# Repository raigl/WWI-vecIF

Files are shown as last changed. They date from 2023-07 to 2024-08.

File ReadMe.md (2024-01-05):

# Whirlwind I Vector Graphics Interface

For showing a Whirlwind programme's output, a small hardware
generates vector strokes on X/Y/Z oszilloskopes
and allows to attach light guns.
Guy Fedorkow's WWI simulator ([https://github.com/gfedorkow/Whirlwind-Instruction-Simulator]) running on a Raspberry (B+) 
can drive the interface and run some original WWI programmes.

## Directories

<dl>
<dt> CAD   <dd> 3D Light gun case 3D files 
<dt> DOC   <dd> Documentation (own and collected)  
<dt> KiCad <dd> Schematics and PCB drawings
<dt> src   <dd> Python and Arduino source
</dl>

## Versions

0.3     Working prototype

1.0     Redesigned

## Basics

The interface allows to draw (short) vectors for two channels
on an analog x/y/z display, e.g. an oszilloscope.
Points are drawn as zero-length vectors.

The D/A converter used has an internal reference of 2.048V, 12 bits
resolution and produces 0..2.047V in steps of 1/4096. 
WWI uses 10 bits plus sign, i.e. +/- 1023.
Thus the coordinate unit corresponds to 1mV internally.
The output state amplifies by 3 (and shifts to zero base), 
thus supplies +/- 3V and 3mV per unit. 

Drawing a vector is done by setting two integrators to the start point,
then provide a speed and start the integrators for 50µs,
which at the same time provides a strobe for the z axis.
With maximum speed (-1023 or +1023, i.e. 0 or 2.047V), the movement is 1/8 of the full coordinate range -1.0 .. +1.0,
i.e. 256 coordinate units or 250mV. 
Thus coordinate differences must be multiplied by 4 to set the speed. 
Longer vectors must be drawn as segments.

The display should be setup such that increasing both coordinates
moves the point right and up.

Character display is not done by hardware as in WWI,
but by software as a chain of segments;
this requires a precise setup of the mid voltage
to 1.023V; otherwise the characters are blurred.

Vector drawing was inspried by the Vectrex gaming console.
Original WWI hardware used a more elaborate method:
A fixed ramp generator (for each coordinate) was multiplied by
the vector delta coordinate provided. 
The advantage is that the end points and do not depend on the precision of the integration capacitor.
Also the strobe start and end could be slightly before and after the end of the ramp, 
ensuring that a chain of vectors has no gaps.

## Displays
 
To display the vectors, the display device must have analog inputs for X/Y mode
and a (digital) Z input for intensitiy modulation.

To better mimic the original, the vector interface board provides
a display bus connector to be used with one or more display tap boards,
which are located directly near a display.

Each display tap board has two switches to select one or both intensification
lines (the original had 15). 

A light gun (light pen) for interactive mode can be connected to a display tap board
and configured for one of two light gun inputs.

Four more switches with lamps (LEDs) can be set by either the user or WWI 
programme.

Displays could in particular be oszilloscopes with a trace blanking
or unblanking input (Z-input).
The amplitude of the X and Y signals is &plusmn;3V which can be attenuated
with a potentiometer on the board.
Z output is 5V (TTL) digital output with 50µs active pulses.
Polarity can be configured on the tap board.

Displays that work without modifications are:
- Grundig GO-40Z oszilloscope (with Z-option)
- Tektronix 1740A oszilloscope 
- Tektronix 611 storage display unit

The Tektronix 611 can be swiched to non-storage mode and is normally 
internally wired for +/- 1V sensitivity; 
thus the potentimeters on the tap board are required.

Several other oscilloscopes have a Z option, but often require
at least 20V to blank the trace.
For this cases, a variant of the tap board has provisions for a voltage converter
and corresponding output amplifier.
Some (e.g. Hameg) are designed for blanking small parts of the trace
only by a diode clamp for the coupling capacitor;
this diode has to be removed or reversed, otherwise the blanking would not work.
 
A Hameg HM512 was succesfully modified by reversing the diode and also
adding internally a small amplifier to obtain larger voltage swing
from the Z-input. 

## I²C Bus

The interface board has a connection to access the Rapi's (second) I²C bus,
shifted to 5V operation.

With upto eight PCF8574, each can drive 8 swiches and lamps.

Note that the WWI had no console, but was to a large extend controlled
by panel switches and lights.

## 5V only operation

The board can be driven by a 5V Arduino.
In this case, JP3 must be cut and changed.
The voltage stablizer U9 (LP 2950-3.3) must be used.
The 3.3V pins are then supplied with 5V.

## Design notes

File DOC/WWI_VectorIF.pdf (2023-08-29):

# Whirlwind I Hardware Vector Interface

Rainer Glaschick, Paderborn 2023-05-13 2023-08-29

# Revision target

For the transition to the revised Interface that will be version 1.0, the planned changes are described below.

Using a display bus and additional tap boards better models the original situation, even if there are currently only two displays useable.

In any case, the selection of the output intensification is done via switches on (or connected to) the tap boards (and not per software).

To have a bank of switches and LEDs, the I²C bus is available on a second connector (4 pins).

## Output

Instead of two outputs for X/Y/Z and two connectors for Lightguns, a display bus is used with tap boards. The number of pins depends on the amount of logic in the tap boards and corresponding flexibility.

In case that rugged connections with proper (round, not ribbon) cables are required, use of the common 15-pin D-SUB connectors is proposed using these lines:

X, Y
Z1, Z2
L1, L2
+5V
GPIO27 (Push-Button)
GPIO5, GPIO6, GPIO20, GPIO21
3x GND

Inversion of the intensification signals Z1 and Z2 is provided on the tap boards, as this uses only two MOS-FETs (and a switch).

The GPIO27 is the same as the key on the interface and may be connected to ground by a momentary push button on the tap board. No LEDs should be connected to this button. Preferred use is as exit if pressed more than 1 sec (software feature).

The other four GPIO lines are logically open-collector lines that can sink upto 2mA each. If grounded by a switch (or key), software can determine the low state (which also lights the LED) and act accordingly.

All GPIO-lines have pullup resistors of 15k (5V) and 10k (3.3V) and are bidirectional converted from 3.3V to 5V, see NXP AN10441.

As a soldering option, instead of GPIO20 and GPIO21, the inverted intensification signals may be used, as this is just a layout option.

If a smaller connector is desired, a 9 pin D-Sub may be used; the pin layout provides X, Y, Z1, Z2, L1, L2, 5V and 2x ground, thus no keys or lamps and no inverted intensification.

On the board, a 2.54mm 2x8 pin header for ribbon connectors is used, pin 16 unused.

## Tap board

A tap board has at least:

two trim potentioemeters (10 kΩ) for the X and Y outputs two (manual) switches to select Z1 or Z2 or both.
one light gun connection
one pushbutton
four switches with LEDs

To select both, Z1 and Z2, schottky diodes driving a 6.8kΩ resistor should work well, although (short) vectors and

Whirlwind I Hardware Vector Interface | 1/5
R. Glaschick, Paderborn | 29.08.23

character segments might be slightly shortened. In that case, CMOS invertes should be used. (The time constant for a 100pF load is 0.68µs, which is less than 2% of the 50µs strobe signal). Another configuration switch (not to be used during normal operation) inverts the intensification signal.

The pushbutton and the switches are described in the previous section.

While two lightguns driving the same line will not damage the system, a configuration jumper should be used to select the light gun input line, not a switch to change it while in operation.

A special tap board may contain a voltage booster providing 30V from the 5V supply to have a larger voltage swing at the Z connector to the display, in particular for older oscilloscopes.

## I²C Bus

By providing the I²C bus on a connector of its own, a bank of panel switches and lights may be connected. Upto 8 PCF 8574 port expanders for 8 lamps or switches may be used.

As with the tap board, the outputs of the port expander are open-drain, here with a dynamic and static pullup.

So each line will lighten the lamp if connected to ground, and either the user or the computer can connect to ground (and light the lamp).

It the computer wants to find out the switches, it would temporarily switch all off and see which ones are still on. Same procedure for the user.

## Reference voltage

A reference of 1.024V is required for the integrators to define the zero speed for displaying points.

The output amplifiers are designed for a 3.3V reference to change the internal 1.024±1.024V to symmetrical ±3.076V.

The board may either use a LP2950-3.3 linear regulator from 5V, or use the 3.3V from the Raspi board directly.

For the integrator's 1.024V, either a trim pot is used to calibrate the voltage.

The output's zero voltage and amplitude is normally not very critical. A voltage divider with 12kΩ and 10kΩ is used giving fairly good results. Place for two larger resistors, e.g. 100kΩ and 150kΩ, is provided for better results, depending on the accuracy of the 3.3V reference.

## 5V protection

A 0.5A fuse is inserted just before the connector to the Raspi. Normally more current can be drawn, only limited by the power supply (minus the current drawn be the Raspi and connected USB perpherals) and the copper tracks on the Raspi. So the tap boards should not use more then 0.4A together, i.e. 0.2A or 1W each for two.

## Integrator switches

The standard 4066 CMOS switches actually work fine; the vertical detours seen on the TEK 611 have not manifested on the oscilloscopes used so far. And because it is only on the horizontal signal, it might be a hardware problem of the TEK 611, Although the datasheet for the 4066 gives gives 50mV crosstalk from the control signal to the data path, it is in the integration path and thus will not propagate to the output. Although Analog Devices produces a better chip (ADG431), a change seems currently not justified, as the 4066 is far better available.

## Intensivation strobe length

A trim potentiometer will allow to precisely set the strobe length of a vector draw. Note that the starting (negative) slope of the intensivation signal must not be delayed, at this would compromise the starting point of the vector, in particular the stroke of a character.

Drawing points is not affected.

## Ribbon input connector

Changed from 26 to 40 pins.

This allows to use additional pins connected to the bus.

# Introduction

To connect a Whirlwind I (WWI) machine (emulated or simulated) to a physical CRT not in raster, but in X-Y-Z-mode, a hardware interface supports drawing of vectors. Single points are drawn as zero-length vectors.

The board has a dual 12-Bit D/A converter (MCP 4822) controlled by SPI, and two digital inputs to set the starting point and to draw a (short) vector with a given velocity.

As a vector is drawn by setting the direction and velocity, the destination point is not defined by its absoulte coordinates. Although the analog hardware is quite precise, the vector size is limited to a fraction of the sceen. Thus, long vectors must be composed from shorter ones, as to restart at a known location.

The board can handle two CRT's and lightguns.

The design was inspired by the Vectrex game console, but allows to set a starting point directly.

# Design

The interface is essentially an settable integrator for X and Y deflection voltages. The output of the board provides ±2.5V on its (analog) output.

Normal use is as follows:

Transmit x and y coordinates of the starting point via SPI to the A/D converter Strobe the doMOVE signal to set initial values of the integrators
Transmit x and y values for the speed via SPI
Strobe the doDRAW signal to draw the vector with the actually set speed

The x and y coordinates are 12 bit values producing an output range of ±2.5V. Thus:

2047 is 0V
0000 is -2.5V
4096 is +2.5V
1024 is -1.25V
3072 is +1.25V.

The duration of the doMOVE signal must be at least 30µs long to have the initial value settled, due to the output resitance of the op amp of about 100Ω to load the 10nF integration capacitor.

It must be inactive again before the draw signal is used.

While the doDRAW (and the doMOVE) signal is inactive, the integrators are halted, i.e. do not change their current value for seconds. Once the doDRAW signal is active, the current x and y values give the (relative) speed at which the coordinates are changed. These are also 12-Bit values with the same encoding as above, i.e. 2047 is zero, which means no change. The values of 0 and 4095 mean full speed in decreasing and increasing the coordinate voltages.

As the time constant of the integrators is 20kΩ*10nF=200µs, a 400µs strobe with maximum speed input (0 or 4097) would be requied to move from one border to the other one. Shorter vectors could be drawn either by decreasing the speed voltage or strobe time. As the controlling computer may not be able to produce short pulses with e.g. 1µs resolution or accuracy, the MOVE pulse is automatically truncated (internally) to 50µs. Thus, the maximum possible move is a difference of 0.25 in either direction which is 12.5% of the screen width. To draw a line from one border to the other, eight or more moves must be used. It is assumend that normally the controlling computer will generate a 60µs pulse and set the speed to control the length of the vector according to a 50µs move. Note that WWI could only draw vectors of half the length.

Although the interface would allow to chain moves without repositioning the starting point, the time to set the starting point should be invested.

An intensification signal for the electron beam (z-axis) is automatically generated while the integration runs, i.e. during the doDRAW signal, thus truncated to 50µs.

## Single point display

In order to show a single point, the starting point is moved to and a vector of zero speed drawn.

## Calculating the speed amount

For each dimension, the speed is calculated by the difference of the end and start coordinate.

Using fixed point numbers for coordinates, the middle of the screen is at (0.0, 0.0) and (-1.0, -1.0) is the lower left corner.

Thus, a maximum speed of -1.0 or +1.0 moves the point by 0.25.

In WWI, the vector length is given in upto 31 steps of 2

-8 units. To move the point one unit, thus the speed must be 4

-6 per unit. As the resolution is 11 bit (without sign), the vector length in the range of 0..31 is multiplied by 64 (and added to 2048 finally).

## Vector intensities

To draw vectors of uniform intensity, the effective speed in the direction of the movement must be the same for all vectors. Then, the length of the vector is determined by the duration of movement.

This may be one reason that the vectors in WWI are limited in length, so that long vectors — if ever required — are shown as a chain of short ones of uniform intensity.

## Drawing circles

Circles should be drawn as short vectors. A number of 60 vectors for a full screen circle is in general visibly satisfying. Multiplying the radius (in the range of 0.0 to 1.0) with 60.0 and truncating the result as integer number of points will speed up small circles. A minimum of 6 points is recommended.

## Character display

Character display is currently done in software by drawing those vectors that are intensified; thus it takes upto 0.7ms per character, as a single line uses 30µs + 60µs = 90µs.

## Lightgun

The lightgun uses a 3-pin connector with ground, +5V and a single input.

The sensor OPL801-OC can be connected without electronics; the input has a pull-up of 4.7kΩ to 5V.

As the controlling computer might not be quick enough to catch a short pulse, it sets a flipflop which is reset with each new position move.

In order to avoid false triggers if the lightgun is pointed outside the screen, only the starting edge is used to set the flip-flop. Continuous light still generates one signal when beginning, but it is unlikely that the right time window will accidentially be used.

There is no electrical correlation of the lightgun with a specific screen. Nevertheless is this no source of confusion, i.e. by giving a trigger if the lighted dot is on a different screen. Of course, if the user of lightgun 2 normally used for screen 2 picks a dot on screen 1, this will be valid and sensed. But as the flag is valid only until the next change in coordinates, it will not be determined by screen 2 unless both show the same dots, in which case it is what is expected.

## More CRTs

To support two (or more) CRTs and lightguns, the deflection circuits remain the same, as the X and Y signals are common to all.

Two additional GPIO outputs enable the corresponding Z-Signals. The polarity is selected for each on board.

One additional input is required for the second light pen.

## Mechanical and electrical hints

The interface is a small board with the following connectors:

Output is a 8-pin connector for the X-, Y- and Z-signals plus a ground pin for each for easier cable connection. The signals are ±2.5V to ground.

Input is wired to 26-pin Raspberry double row pinning for simple connection to the latter; to use an Arduino, a shield providing this connector is recommended.

The SPI interface must use the levels defined by VADC, which is normally either 3.3V or 5.0V. The D/A-converter works from 2.7 to 5.5V, as it has an internal referece of 2.048V. So it may be used with Raspberry Pi boards at 3.3V and also with older design that use 5V logical levels.

The +5V input is used as supply for the internal logic and as reference for the conversion to ±2.5V; the necessary negative supply is generated on board.

The two logic inputs may be any logic; <2V for inactive and >3V for active.

The GPIO Pins used are (besides SPI):

17: Move to vector start position
22: Draw vector for 50µs
23: Enable Z-strobe 1
24: Lightgun 1 input
25: Lightgun 2 input
18: Enable Z strobe 2
27: Keyswitch on board

# Various

## Z-inputs

For some Oszilloscopes with Z-input (e.g. HM 512-2), the signal is assumed to be short negative pulses darkening a (small part) of the signal shown as a time or event marker. As the coupling is via capacitor to the high voltage, a clamp diode is required to determine the default without pulses. This diode is often such that negative pulses reduce the intensity, so that normally the beam is visible. To support positive pulses to show the beam, the diode must be reversed. If a switch is used, check for sufficient voltage withstanding, or use an appropriate relay.

## Split power

The current design uses a D/A converter (MCP4821) that runs equally well from 3.3V and 5.0V supplies, including logic, if 1.024±1.024V are selected.

All logic in- and outputs use MOS-FETs (2N7000) that allow both voltage levels.

The analog section uses the output voltage range of the D/A converter, i.e. 0V to 2.048V, with 1.024V as analog reference zero. An output stage converts this to ±2.5V; the required negative supply is provided on board.

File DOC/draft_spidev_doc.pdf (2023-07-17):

## SpiDev Documentation

(Draft version 2020-07-12)

### 1. Table of Content

### 1. Description

This module defines an object type that allows SPI transactions on hosts running the Linux kernel. The host kernel must have SPI support and SPI device interface support. All of these can be either built-in to the kernel, or loaded from modules.

SpiDev Documentation (2020-07-12 draft) | 2/10

This document is written for any Raspberry Pi model running recent versions of Raspbian Buster and the current (July 2020) version of Raspberry Pi OS. It could apply to other systems using different Linux distributions with slight changes.
Details can be found at https://sigmdel.ca/michel/ha/rpi/spi_on_pi_en.html.

### 2. SpiDev Installation

In a Python3 virtual environment, the spidev module can be installed with a simple pip command:
(spipy) pi@raspberrypi:~ $ pip install spidev
The module can be installed in the default Python3 installation with the following:
pi@raspberrypi:~ $ sudo apt install python3-spidev
From .../site-packages/spidev-3.4.dist-info/METADATA
Name: spidev
Version: 3.4
Summary: Python bindings for Linux SPI access through spidev Home-page: http://github.com/doceme/py-spidev

### 3. SPI kernel drivers

By default, the SPI kernel drivers are not loaded in Raspbian Buster Lite. That can be done on a one-off basis with the dtparam utility: pi@raspberrypi:~ $ sudo dtparam spi=on
This will create two spi devices: /dev/spidev0.0 and /dev/spidev0.1.
To add the driver automatically at each boot, edit the /boot/config.txt file or use the raspi-config utility.
Signal | GPIO pin | Physical pin
SPI0_MOSI | 10 | 19
SPI0_MISO | 9 | 21
SPI0_SCLK | 11 | 23
SPI0_CEO_N | 8 | 24
SPI0_CE1_N | 7 | 26
SPI0 connections

Raspberry Pi models with 40 ping GPIO headers have a second SPI bus which can be enabled with the dtoverlay utility:
pi@raspberrypi:~ $ sudo dtoverlay spi1-3cs
This will create three devices: /dev/spidev1.0 , /dev/spidev1.1 and /dev/spidev1.2.
Signal | GPIO pin | Physical pin
SPI1_MOSI | 20 | 38
SPI1_MISO | 19 | 35
SPI1_SCLK | 21 | 40
SPI1_CEO_N | 18 | 22
SPI1_CE1_N | 17 | 11
SPI1_CE2_N | 16 | 36
SPI1 connections
Other overlays are available with fewer chip select signals ( spi1-2cs and spi1-cs).
The Raspberry Pi model 4 and the Compute Module has even more SPI buses.

### 4. Permission

Because the SPI device interface is used to read and write, users of a SPI device node must have root permissions. However, in Raspbian Buster and Raspberry Pi OS members of the spi group have access to the interface and the default user is a member of that group. Hence it will not be necessary to use the sudo prefix when running a Python script that imports spidev.

### 5. Examples

Simple output
This example will open SPI and writes a byte (0x3A) every tenth of a second until Ctrl+C is pressed.

import spidev
import time
spi = spidev.SpiDev(0, 1) | # create spi object connecting to /dev/spidev0.1
spi.max_speed_hz = 250000 | # set speed to 250 Khz

try:
while True: | # endless loop, press Ctrl+C to exit

spi.writebytes([0x3A]) # write one byte
time.sleep(0.1) | # sleep for 0.1 seconds

finally:
spi.close() | # always close the port before exit
Reverse bits
This script will reverse the bit ordering in one byte (if you are not able to change LSB / MSB first to your needs.

def ReverseBits(byte):
byte = ((byte & 0xF0) >> 4) | ((byte & 0x0F) << 4)
byte = ((byte & 0xCC) >> 2) | ((byte & 0x33) << 2)
byte = ((byte & 0xAA) >> 1) | ((byte & 0x55) << 1)
return byte
Print bytes
This script will print out a byte array in a human readable format (hexadecimal). This is often useful during debugging.

def BytesToHex(Bytes):
return ''.join(["0x%02X " % x for x in Bytes]).strip()

### 6. Class Constructors

spidev()
Syntax: myspi = spidev()
Remark: This is the base constructor which does not connect the object to a system SPI device. It will be necessary to use the open() method to associate the object with a device.

spidev(bus, cs)
Syntax: myspi = spidev(bus, cs)
Remark: this is an overloaded constructor that creates the object and connects it to a system SPI device. So
myspi = spidev(bus, cs);
and
myspi = spidev();
myspi.open(bus, cs);
are equivalent.
On the Raspberry Pi, the max_speed_hz attribute should be set to a reasonable value (less than or equal to 32 MHz) after the spidev object is connected to a system SPI device either with the spidev(bus, cs) constructor or the open(bus, cs) method.

### 7. Class Attributes

bits_per_word
Description: Number of bits per word. Default: 8
Range: 8 .. 16
Restrictions: Read-only on the Raspberry Pi.

cshigh
Description: If true the chip select signal is active high otherwise it is active low.
Default: False (chip select is active low).

loop
Description: If true the “loop back configuration” is enabled.
Default: False
Remarks: Read-only on the Raspberry Pi. This is used for test purposes; anything that gets received will be echoed back (presumably that means anything received on MISO line is echoed to the MOSI line. A loop back on a single SPI port can be done by connecting its MISO and MOSI lines together.

lsbfirst
Description: Boolean property that specifies if a word is transmitted with the least significant bit first or not (which, of course, means that it would be transmitted most significant bit first).
Default: False (most significant bit first)
Restrictions: Read-only in Raspbian Buster. The default value seems to depend on the bit endianness of the system. The Raspberry Pi can only send most significant bit first, so it may be necessary to convert the byte(s) manually (see code examples for such a script) when a slave device expects to receive bytes least significant bit first and sends its own data in the same way.

max_speed_hz
Description: Property that specifies the maximum bus speed in Hz. Default: 125000000
Remarks: The 125 MHz default value is not sustainable on a Raspberry Pi and it must be changed to a reasonable value. The maximum speed appears to be about 32 MHz on the Raspberry Pi. There is a debate about permissible speed values, with some insisting that the speed must be a power of 2, while others argue that it can be a multiple of 2. Tests at least partially confirm that the latter is correct. It was possible to set the speed at 3800 Hz, which appears to be a lower limit, and at 4800 Hz. Neither of these values is a power of 2.

mode
Description: the SPI mode as a two-bit pattern of Clock Polarity and Clock Phase.
Default: 0
Range: 0 to 3
Mode | clock polarity (CPOL) | clock phase (CPHA)
0 | 0 | 0
1 | 0 | 1
2 | 1 | 0
3 | 1 | 1

threewire
Description: If true, the SPI device is set in three wire mode which means the MISO and MOSI signals share a single date line. In effect, the protocol becomes half duplex.
Default: False
Remark: Not tested!

### 8. Class Methods

close
Syntax: close()
Returns: None
Description: Disconnects the object from the system SPI device.

open
Syntax: open(bus, cs)
Description: Connects the object to the specified system PI device. Example: open(1,2) will open /dev/spidev1.2
Remark: Of course, the kernel driver for the device must be loaded.

readbytes
Syntax: readbytes(len)
Returns: [values]
Description: Read a list of len values (bytes) from SPI device.

writebytes
Syntax: writebytes([values])
Returns: None
Description: Write a list of bytes to the SPI device.
Remark: Fails if the list of values is bigger than the maximum buffer size. In Raspbian Buster this limit is 4096 bytes. For longer lists use writebytes2.
This is not a SPI transaction, all data read from the MISO signal is discarded and the list of values is not modified.

writebytes2
Syntax: writebytes2([values])
Returns: None
Description: Write a list of bytes of any size to the SPI device.

Remarks: Unlike writebytes, which fails if the list of values is greater than the maximum buffer size, writebytes2 handles long lists by breaking it into chunks sent out one at a time. The size of each chunk is equal to the maximum buffer size except perhaps for the last one which could be smaller. The chip select signal is released between each chunk.
Also, writebytes2 understands the buffer protocol (https://docs.python.org/3/c-api/buffer.html) so it can accept numpy (https://numpy.org/) byte arrays for example without need to convert them with tolist() first. This offers much better performance when transferring frames to SPI displays for instance.
This is not a SPI transaction, all data read from the MISO signal is discarded and the list of values is not modified.

xfer
Syntax: | rcvd = xfer([values])
| rcvd = xfer([values], speed)
| rcvd = xfer([values], speed, delay)
| rcvd = xfer([values], speed, delay, bits)
Returns: [values]
Description: Perform a SPI transaction: a list of bytes is written to the SPI device and as each byte in that list is sent out, it is replaced by the data simultaneously read from the SPI slave device over the MISO line. Remarks: Fails if the list of values is bigger than the maximum buffer size which is 4,096 bytes. To send longer lists of values use xfer3.
While the documentation says that the “chip select signal will be released and reactivated between blocks”, this does not make much sense as this function sends only one block of data with at most 4096 bytes of data in Raspbian Buster.
If speed is not specified, the SPI clock is set to the maximum_speed_hz attribute. If the speed is specified (in Hz) it will be used for that single transaction and will not modify the value of maximum_speed_hz attribute of the object.
If delay is not specified, assume the value is 0. The chip select line remains asserted for a short time after all the data has been transmitted, however, if a delay is specified, the chip select will remain asserted for that additional time (in microseconds).

The bits (per word) parameter can have only one value, 8, in the Raspberry Pi.

xfer2
Syntax: | rcvd = xfer2([values])
| rcvd = xfer2([values], speed)
| rcvd = xfer2([values], speed, delay)
| rcvd = xfer2([values], speed, delay, bit
Remark: The documentation says “Contrary to xfer, the chip select signal will be held active between blocks” but this does not seem to be borne out. There does not seem to be any difference between xfer and xfer2. The speed, delay and bit options have the same effect as in the xfer function as explained above.

xfer3
Syntax: | rcvd = xfer3([values])
| rcvd = xfer3([values], speed)
| rcvd = xfer3([values], speed, delay)
| rcvd = xfer3([values], speed, delay, bit
Returns: [values]
Description: Perform a SPI transaction: a list of bytes of arbitrary size is written to the SPI device and as each byte in that list is sent out, it is replaced by the data simultaneously read from the SPI slave device over the MISO line.
Remark: Unlike xfer and xfer2, which fail if the list of values is greater than the maximum buffer size, xfer3 handles a long list by breaking it into chunks sent out one at a time. The size of each chunk is equal to the maximum buffer size except perhaps for the last one which could be smaller.
The chip select signal is released between each chunk for approximately a fifth of a milliseconds and indefinitely after the last chunk of data is sent. If a delay is specified, the chip select line will remain asserted for that period of time at the end of the transmission of each block of data before being released.

### 9. Maximum SPI Buffer Size

The data to be sent out by a SPI device using any of the writebytes and xfer methods is buffered. The size of the latter is seemingly specified in the /sys/module/spidev/parameters/bufsiz.

pi@rasberrypi:~ $ cat /sys/module/spidev/parameters/bufsiz
4096

That value can be changed by adding a spidev.bufsiz=xxxx option (where xxxx is the needed buffer size) in the /boot/cmdline.txt file. Remember to keep the content of that file on a single line. The system has to be rebooted for this change to take effect.
No matter what value is assigned to bufsiz, the writebytes, xfer and xfer2 functions use a fixed buffer size of 4096 bytes and will not transfer any more data. The writebytes2 and xfer3 will use the specified buffer size when sending bigger lists.

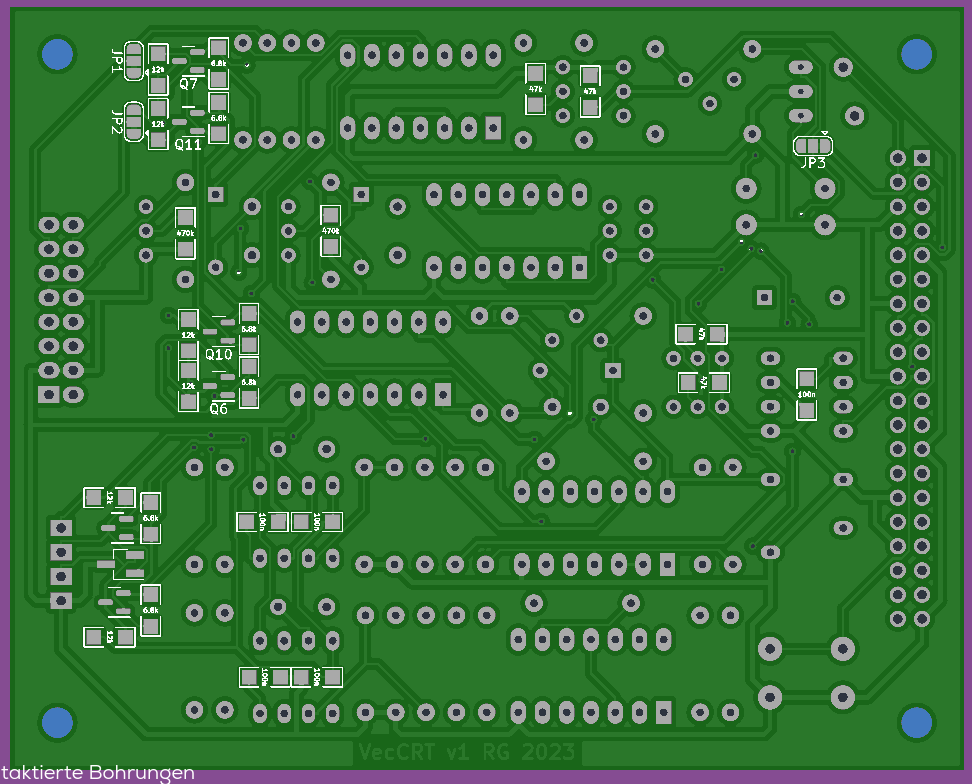
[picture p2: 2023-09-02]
KiCad/VecCRT_back_1.0c.png

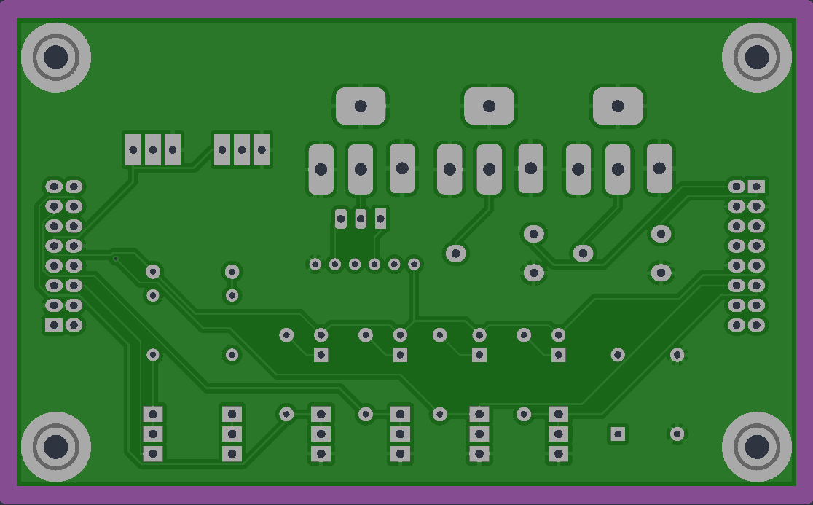
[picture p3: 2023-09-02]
KiCad/VecCRTtap_back.png

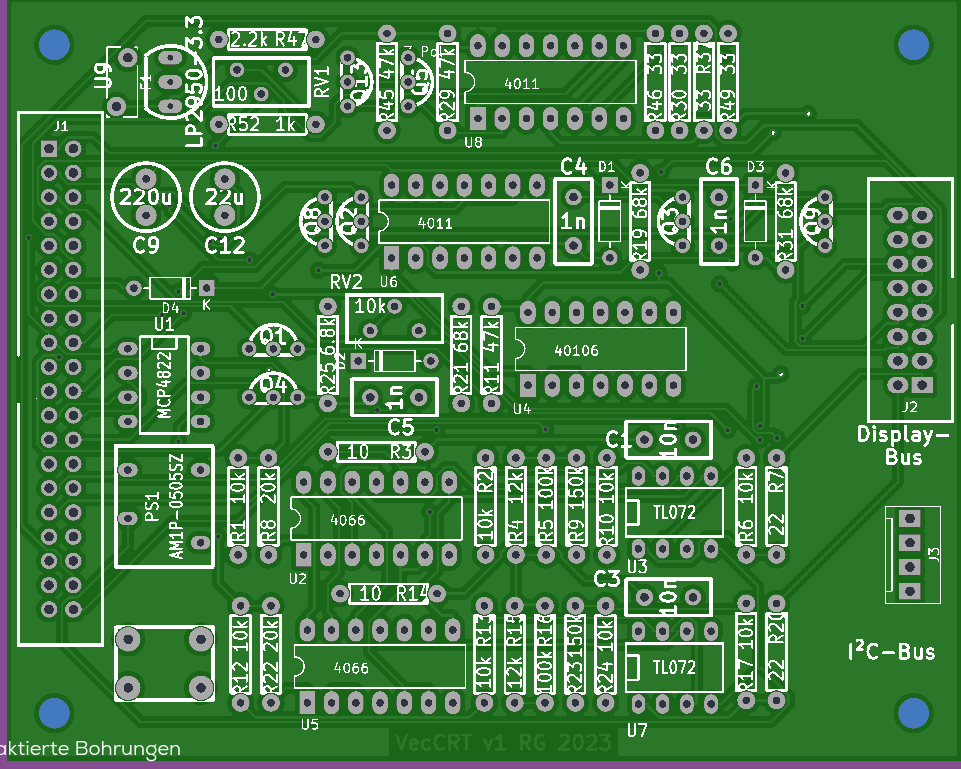
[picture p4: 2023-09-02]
KiCad/VecCRT_front_1.0c.png

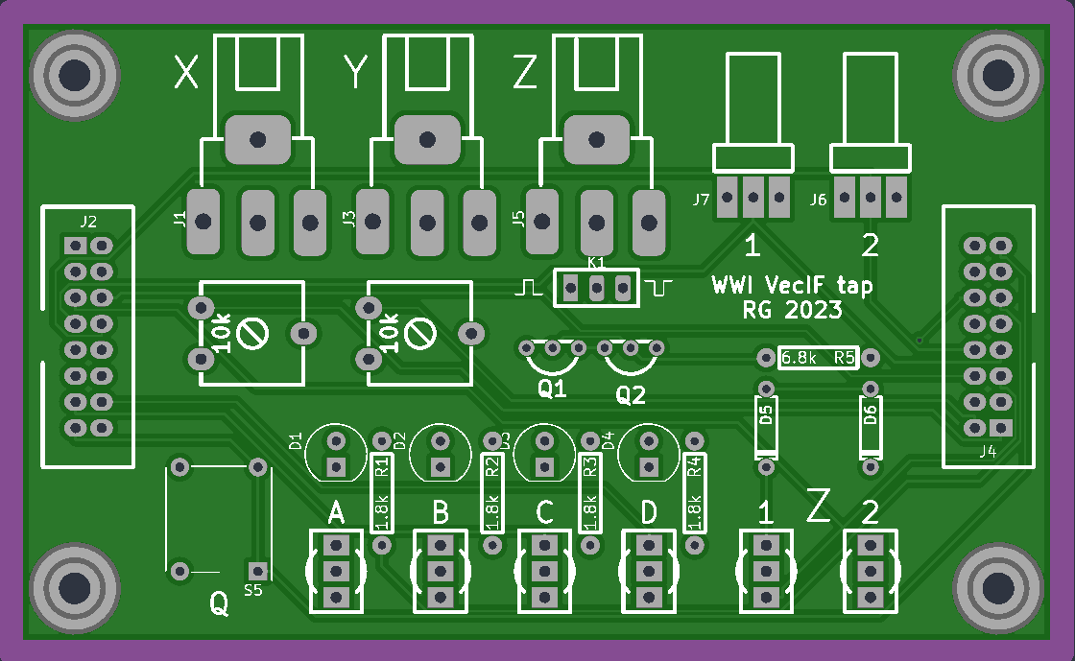
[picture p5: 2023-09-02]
KiCad/VecCRTtap_front.png

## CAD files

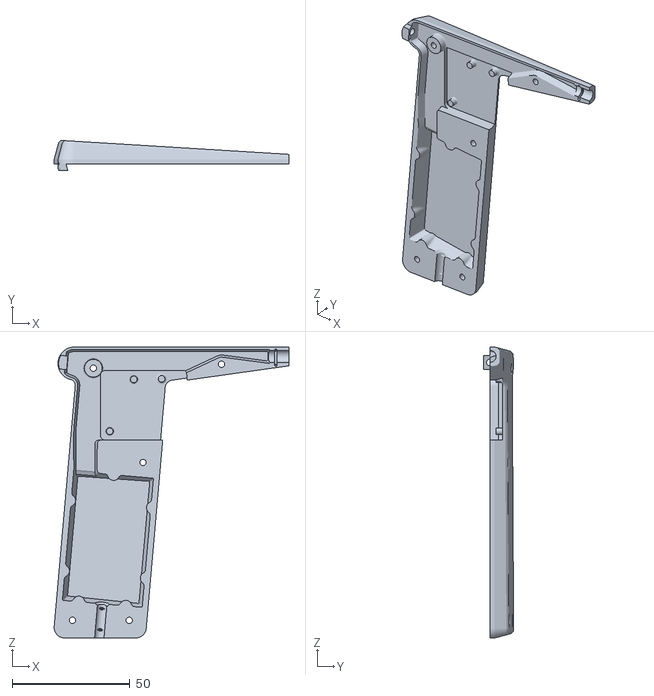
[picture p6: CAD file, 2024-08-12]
CAD/Lightgun_bottom.stl
99.6 x 12.8 x 123.5

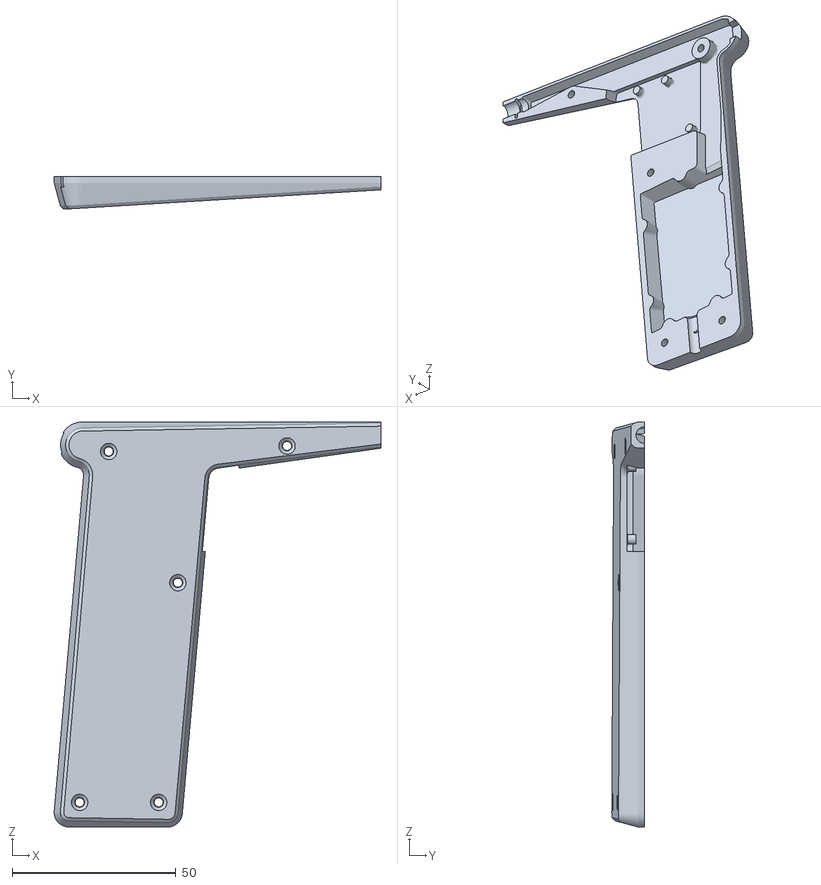
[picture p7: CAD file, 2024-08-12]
CAD/Lightgun_top.stl
99.6 x 9.91 x 123.5

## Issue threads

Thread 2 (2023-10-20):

Boards for sale?

larsbrinkhoff, 2023-10-20:
Hello,

I wonder if you will have boards for sale?  I'm interesting in using them to emulate DEC Type 30, 340, GT40, and Imlac PDS-1 displays.

Thanks!

raigl, 2024-02-12:
Hello,
sorry I did not see your comment, as I am still learning how to use git/github.
While it would not be a real problem to ship them within the EU, I fear that they are of no real use.
To try it, I may give you one of the previoius version, which does not have the display bus, but should work otherwise.
If you are still interested, drop me a line.
Rainer

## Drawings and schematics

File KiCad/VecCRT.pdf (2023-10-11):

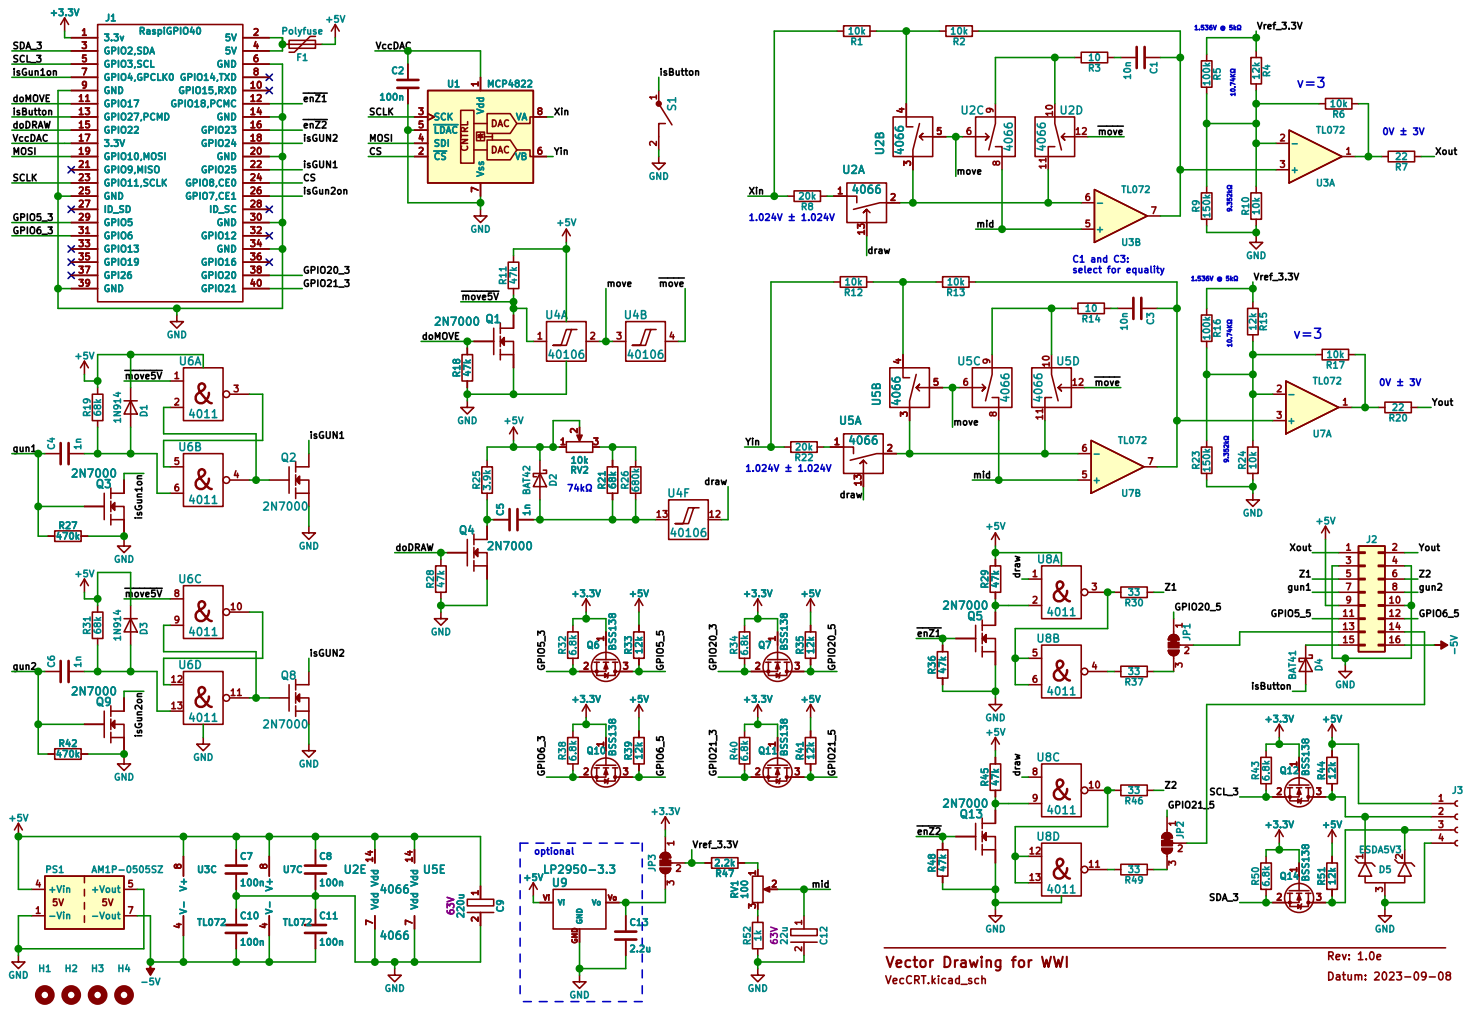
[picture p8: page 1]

0V þÿ±3V þÿ9.352k© C1 and C3: select for equality

9 | 10
11 | 12
13 | 14

Rev: 1.0e Vector Drawing for WWI

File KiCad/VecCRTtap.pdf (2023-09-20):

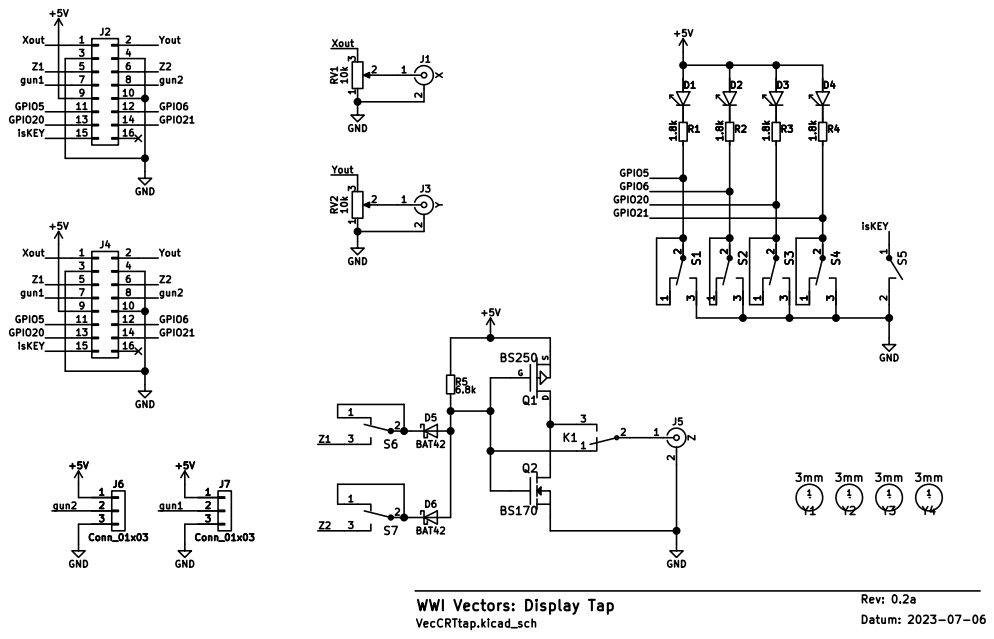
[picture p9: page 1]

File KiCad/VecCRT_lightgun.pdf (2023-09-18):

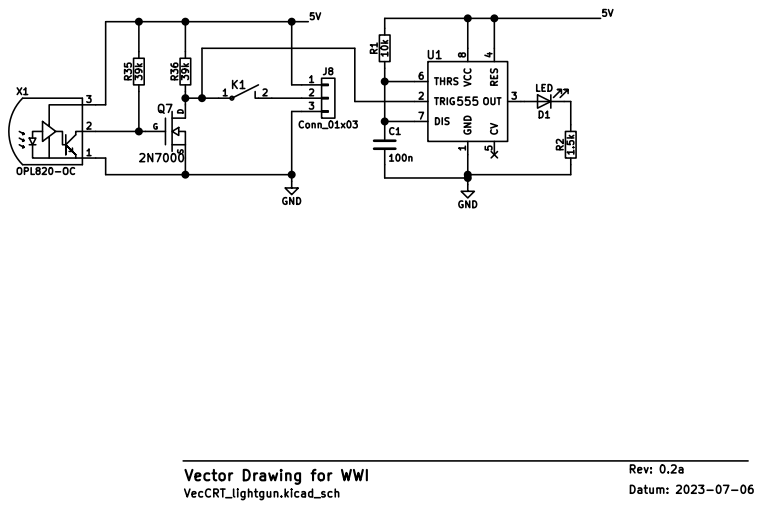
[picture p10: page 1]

Rev: 0.2a Vector Drawing for WWI

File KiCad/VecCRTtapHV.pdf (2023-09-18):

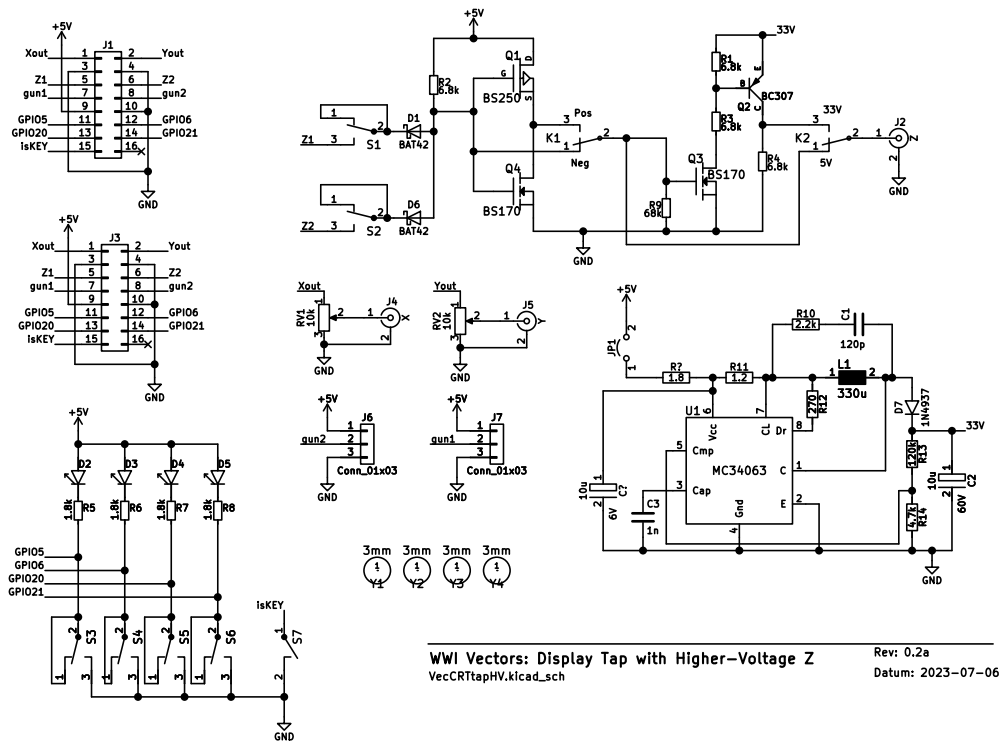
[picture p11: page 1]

9 | 10
11 | 12
13 | 14
15 | 16

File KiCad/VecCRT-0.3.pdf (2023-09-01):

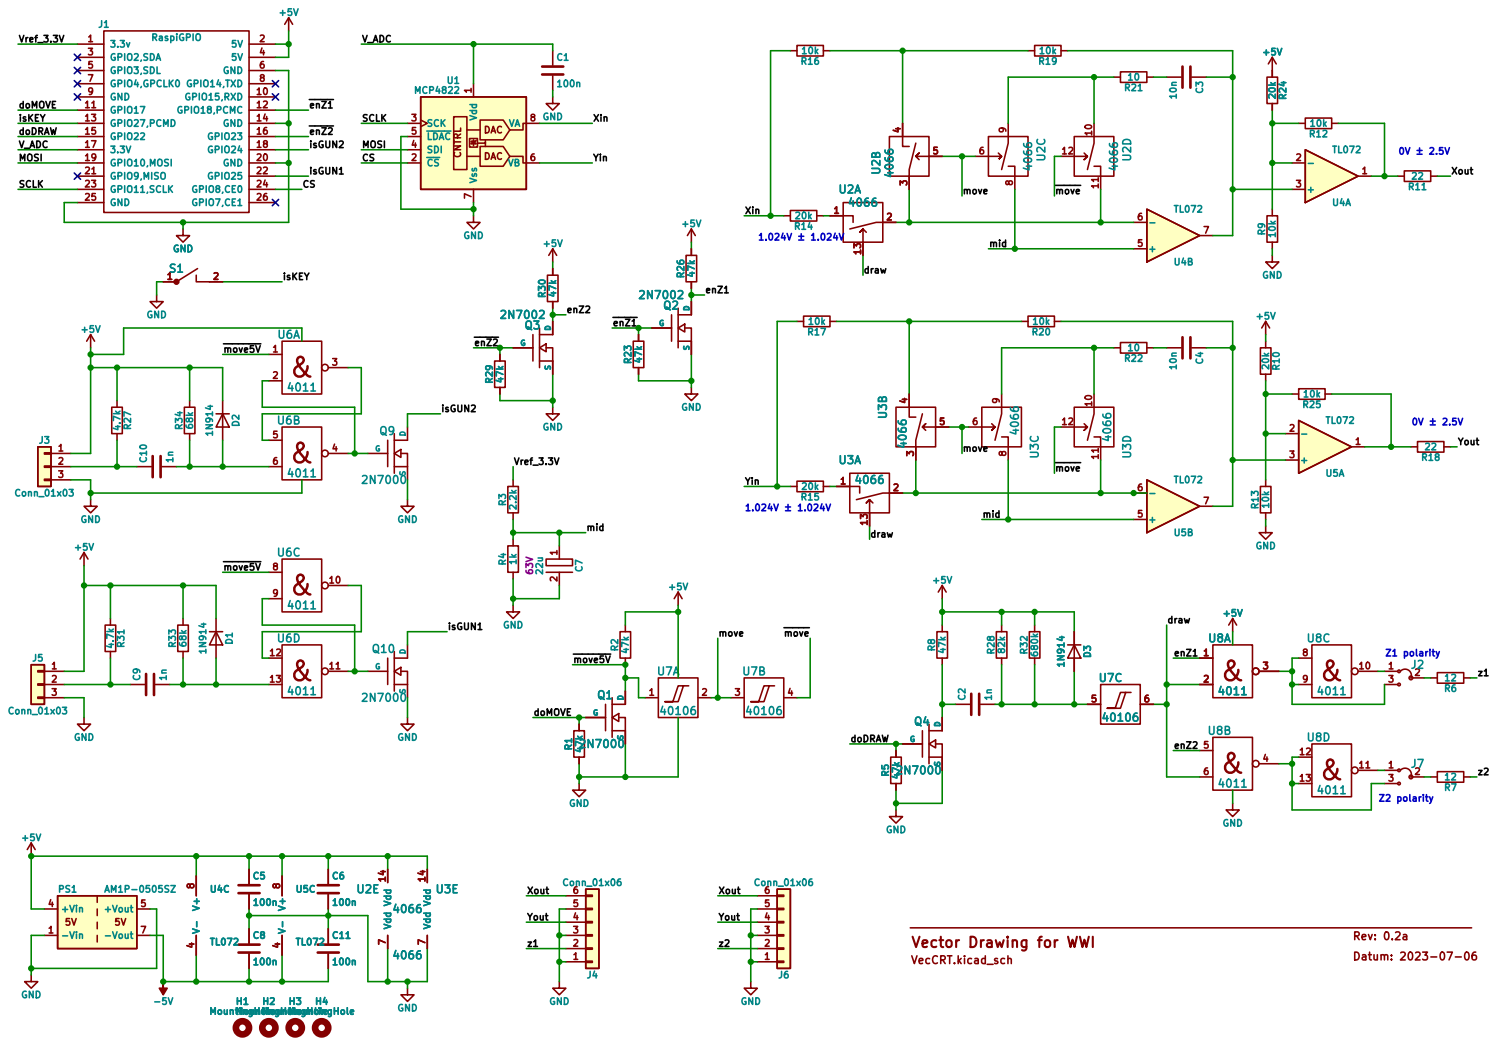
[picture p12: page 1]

Rev: 0.2a Vector Drawing for WWI

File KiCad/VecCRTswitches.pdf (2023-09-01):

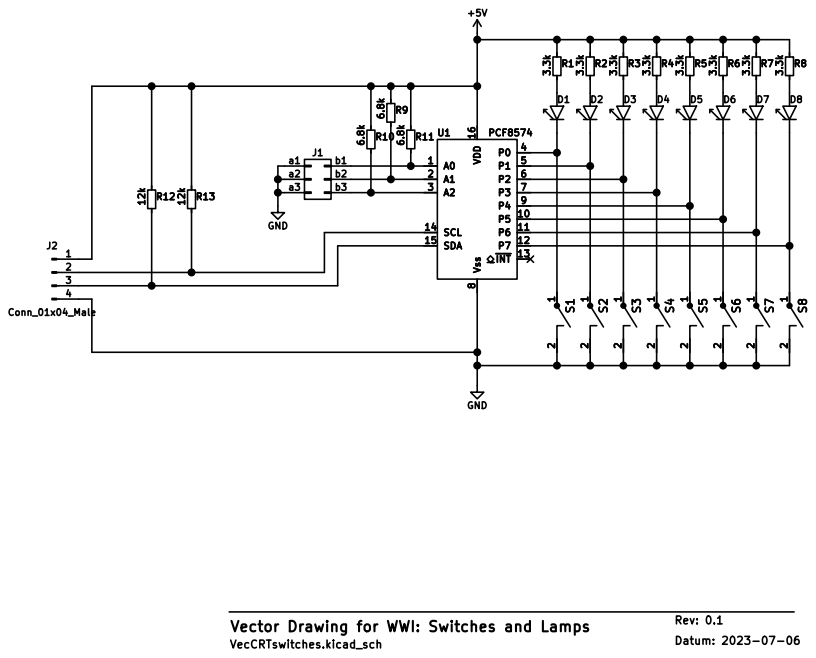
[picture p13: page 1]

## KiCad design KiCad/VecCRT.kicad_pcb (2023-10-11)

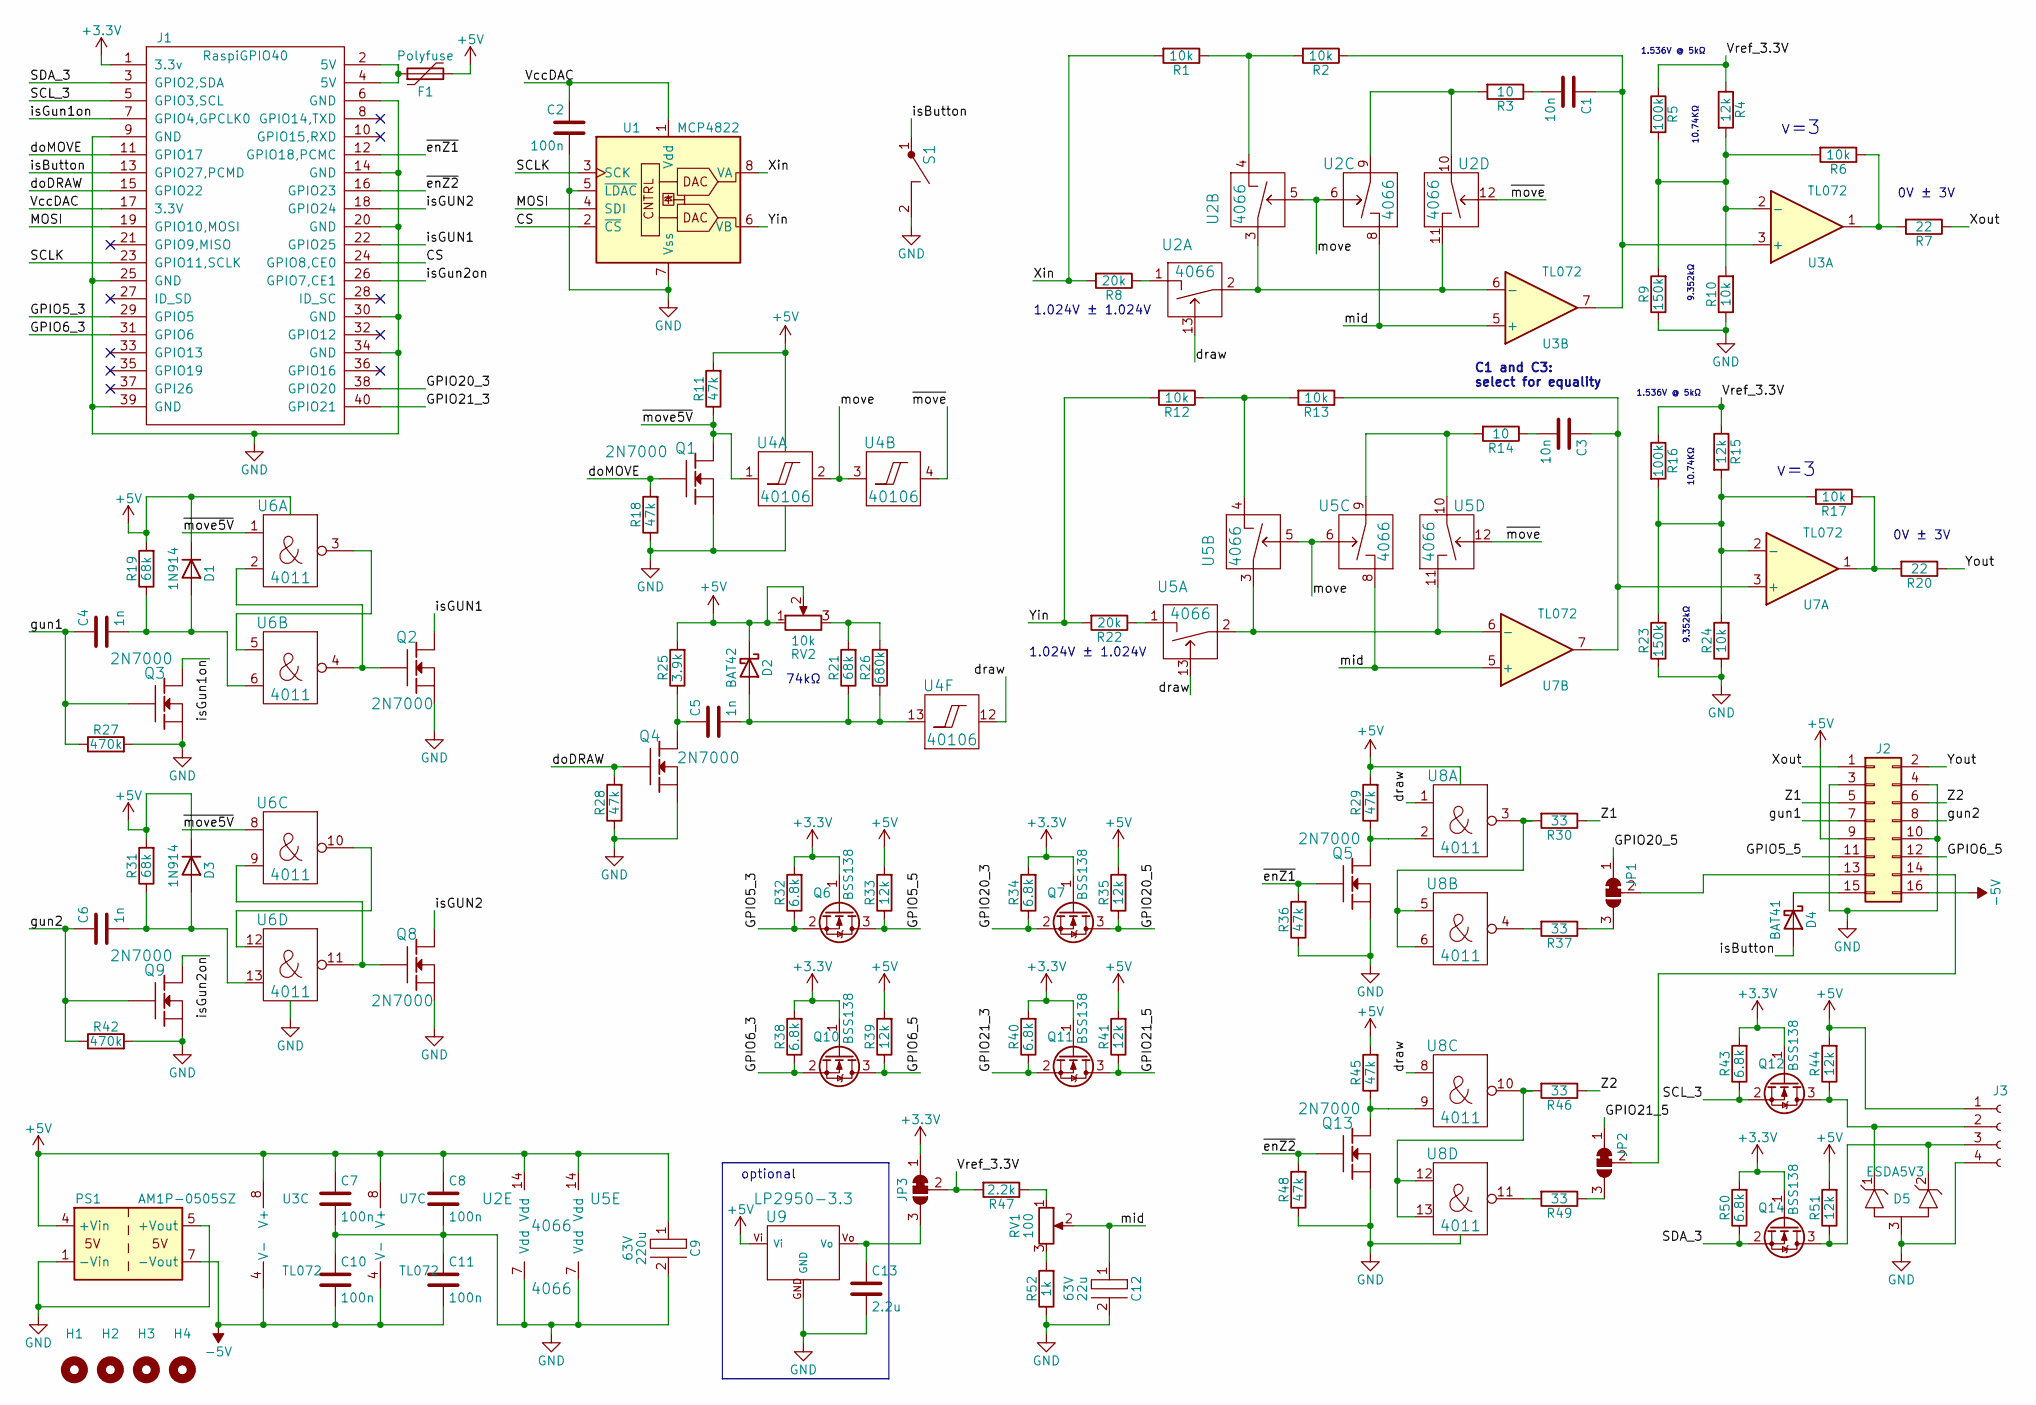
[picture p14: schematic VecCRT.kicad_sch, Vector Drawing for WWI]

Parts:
C1, C3: 10n; C2-2
C2, C7, C8, C10, C11: 100n; SM-1206B
C4, C5, C6: 1n; C2-2
C9: 220u; C2-7; Voltage 63V
C12: 22u; C2-7; Voltage 63V
C13: 2.2u; SM-1206B
D1, D3: 1N914; D_DO-35_SOD27_P7.62mm_Horizontal
D2: BAT42; D_DO-35_SOD27_P7.62mm_Horizontal
D4: BAT41; D_DO-35_SOD27_P7.62mm_Horizontal
D5: ESDA5V3; SOT-23_Handsoldering
F1: Polyfuse; Fuse_Bourns_MF-RG300
H1, H2, H3, H4: MountingHole; MountingHole_3.2mm_M3
J1: RaspiGPIO40; Wannenstecker_2x20_V
J2: Conn_02x08_Odd_Even; Wannenstecker_2x08_V
J3: Conn_01x04_Female; PSS_4
JP1, JP2: SolderJumper_3_Open; SolderJumper-3_P1.3mm_Bridged12_RoundedPad1.0x1.5mm
JP3: SolderJumper_3_Bridged12; SolderJumper-3_P1.3mm_Bridged12_RoundedPad1.0x1.5mm
PS1: AM1P-0505SZ; AM1P-SZ
Q1, Q2, Q3, Q4, Q5, Q8, Q9, Q13: 2N7000; FETsgd_inline
Q6, Q7, Q10, Q11, Q12, Q14: BSS138; SOT-23
R1, R2, R6, R10, R12, R13, R17, R24: 10k; R4-2
R3, R14: 10; R4-2
R4, R15: 12k; R4-2
R5, R16: 100k; R4-2
R7, R20: 22; R4-2
R8, R22: 20k; R4-2
R9, R23: 150k; R4-2
R11, R29, R45: 47k; R4-2
R18, R28, R36, R48: 47k; SM-1206B
R19, R21, R31: 68k; R4-2
R25: 3.9k; R4-2
R26: 680k; SM-1206B
R27, R42: 470k; SM-1206B
R30, R37, R46, R49: 33; R4-2
R32, R34, R38, R40, R43, R50: 6.8k; SM-1206B
R33, R35, R39, R41, R44, R51: 12k; SM-1206B
R47: 2.2k; R4-2
R52: 1k; R4-2
RV1: 100; Pot64y
RV2: 10k; Pot64y
S1: TASTER; Tast2mil
U1: MCP4822; DIP-8_300
U2, U5: 4066; DIP-14_W7.62mm_LongPads
U3, U7: TL072; DIP-8_300
U4: 40106; DIP-14_W7.62mm_LongPads
U6, U8: 4011; DIP-14_W7.62mm_LongPads
U9: LP2950-3.3; TO-92ViGNDVo

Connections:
+3.3V: J1.1 (3.3v), JP3.1 (A), Q6.1 (G), Q7.1 (G), Q10.1 (G), Q11.1 (G), Q12.1 (G), Q14.1 (G), R32.2, R34.2, R38.2, R40.2, R43.2, R50.2
+5V: C7.1, C8.1, C9.1, D1.1 (K), D2.1 (K), D3.1 (K), F1.2, J2.9, J3.1, PS1.4 (+Vin), R11.2, R19.2, R25.2, R29.2, R31.2, R33.2, R35.2, R39.2, R41.2, R44.2, R45.2, R51.2, RV2.1, RV2.2, U2.14 (Vdd), U3.8 (V+), U4.14, U5.14 (Vdd), U6.14 (VDD), U7.8 (V+), U8.14 (VDD), U9.Vi
-5V: C10.2, C11.2, J2.16, PS1.7 (-Vout), U3.4 (V-), U7.4 (V-)
/CS: J1.24 (GPIO8,CE0), U1.2 (~CS)
/GPIO5_3: J1.29 (GPIO5), Q6.2 (S), R32.1
/GPIO5_5: J2.11, Q6.3 (D), R33.1
/GPIO6_3: J1.31 (GPIO6), Q10.2 (S), R38.1
/GPIO6_5: J2.12, Q10.3 (D), R39.1
/GPIO20_3: J1.38 (GPIO20), Q7.2 (S), R34.1
/GPIO20_5: JP1.1 (A), Q7.3 (D), R35.1
/GPIO21_3: J1.40 (GPIO21), Q11.2 (S), R40.1
/GPIO21_5: JP2.1 (A), Q11.3 (D), R41.1
/MOSI: J1.19 (GPIO10,MOSI), U1.4 (SDI)
/SCLK: J1.23 (GPIO11,SCLK), U1.3 (SCK)
/SCL_3: J1.5 (GPIO3,SCL), Q12.2 (S), R43.1
/SDA_3: J1.3 (GPIO2,SDA), Q14.2 (S), R50.1
/VccDAC: C2.1, J1.17 (3.3V), U1.1 (Vdd)
/Vref_3.3V: JP3.2 (C), R4.1, R5.1, R15.1, R16.1, R47.2
/Xin: R1.2, R8.2, U1.8 (VA)
/Xout: J2.1, R7.1
/Yin: R12.2, R22.2, U1.6 (VB)
/Yout: J2.2, R20.1
/Z1: J2.5, R30.1
/Z2: J2.6, R46.1
/doDRAW: J1.15 (GPIO22), Q4.G, R28.2
/doMOVE: J1.11 (GPIO17), Q1.G, R18.2
/draw: U2.13, U4.12, U5.13, U8.1, U8.8
/gun1: C4.1, J2.7, Q3.G, R27.1
/gun2: C6.1, J2.8, Q9.G, R42.1
/isButton: D4.2 (A), J1.13 (GPIO27,PCMD), S1.1
/isGUN1: J1.22 (GPIO25), Q2.D
/isGUN2: J1.18 (GPIO24), Q8.D
/isGun1on: J1.7 (GPIO4,GPCLK0), Q3.D
/isGun2on: J1.26 (GPIO7,CE1), Q9.D
/mid: C12.1, RV1.2, U2.8, U3.5 (+), U5.8, U7.5 (+)
/move: U2.5, U2.6, U4.2, U4.3, U5.5, U5.6
/~enZ1: J1.12 (GPIO18,PCMC), Q5.G, R36.2
/~enZ2: J1.16 (GPIO23), Q13.G, R48.2
/~move5V: Q1.D, R11.1, U4.1, U6.1, U6.8
/~move: U2.12, U4.4, U5.12
GND: C2.2, C7.2, C8.2, C9.2, C10.1, C11.1, C12.2, C13.2, D5.3 (A), J1.6 (GND), J1.9 (GND), J1.14 (GND), J1.20 (GND), J1.25 (GND), J1.30 (GND), J1.34 (GND), J1.39 (GND), J2.3, J2.4, J2.10, J3.4, PS1.1 (-Vin), PS1.5 (+Vout), Q1.S, Q2.S, Q3.S, Q4.S, Q5.S, Q8.S, Q9.S, Q13.S, R9.1, R10.1, R18.1, R23.1, R24.1, R27.2, R28.1, R36.1, R42.2, R48.1, R52.1, S1.2, U1.5 (~LDAC), U1.7 (Vss), U2.7 (Vdd), U4.7 (e), U5.7 (Vdd), U6.7 (VSS), U8.7 (VSS), U9.GND
unnamed: C1.1, R2.1, U3.3 (+), U3.7
unnamed: C1.2, R3.1
unnamed: C3.1, R13.1, U7.3 (+), U7.7
unnamed: C3.2, R14.1
unnamed: C4.2, D1.2 (A), R19.1, U6.6
unnamed: C5.1, Q4.D, R25.1
unnamed: C5.2, D2.2 (A), R21.1, R26.1, U4.13
unnamed: C6.2, D3.2 (A), R31.1, U6.13
unnamed: C13.1, JP3.3 (B), U9.Vo
unnamed: D4.1 (K), J2.15
unnamed: D5.1 (K1), J3.2, Q12.3 (D), R44.1
unnamed: D5.2 (K2), J3.3, Q14.3 (D), R51.1
unnamed: F1.1, J1.2 (5V), J1.4 (5V)
unnamed: J2.13, JP1.2 (C)
unnamed: J2.14, JP2.2 (C)
unnamed: JP1.3 (B), R37.1
unnamed: JP2.3 (B), R49.1
unnamed: Q2.G, U6.2, U6.4
unnamed: Q5.D, R29.1, U8.2
unnamed: Q8.G, U6.9, U6.11
unnamed: Q13.D, R45.1, U8.9
unnamed: R1.1, R2.2, U2.4
unnamed: R3.2, U2.9, U2.10
unnamed: R6.1, R7.2, U3.1
unnamed: R8.1, U2.1
unnamed: R4.2, R5.2, R6.2, R9.2, R10.2, U3.2 (-)
unnamed: R12.1, R13.2, U5.4
unnamed: R14.2, U5.9, U5.10
unnamed: R15.2, R16.2, R17.2, R23.2, R24.2, U7.2 (-)
unnamed: R17.1, R20.2, U7.1
unnamed: R21.2, R26.2, RV2.3
unnamed: R22.1, U5.1
unnamed: R30.2, U8.3, U8.5, U8.6
unnamed: R37.2, U8.4
unnamed: R46.2, U8.10, U8.12, U8.13
unnamed: R47.1, RV1.1
unnamed: R49.2, U8.11
unnamed: R52.2, RV1.3
unnamed: U2.2, U2.3, U2.11, U3.6 (-)
unnamed: U5.2, U5.3, U5.11, U7.6 (-)
unnamed: U6.3, U6.5
unnamed: U6.10, U6.12

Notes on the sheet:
0V ± 3V
74kΩ
v=3
10.74KΩ
9.352kΩ
1.536V @ 5kΩ
1.024V ± 1.024V
C1 and C3: select for equality
optional

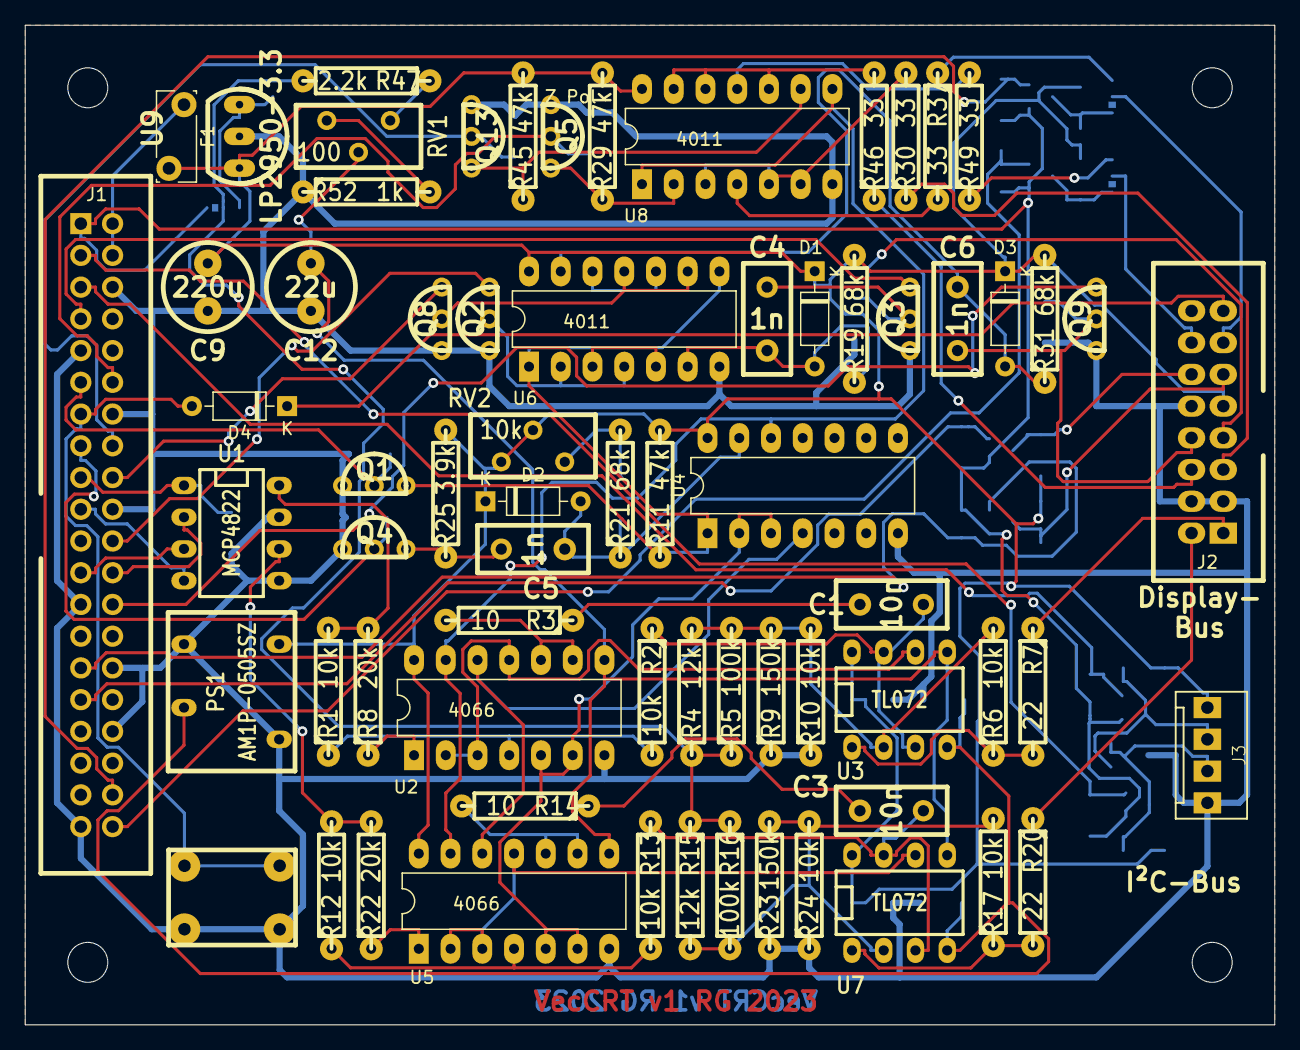
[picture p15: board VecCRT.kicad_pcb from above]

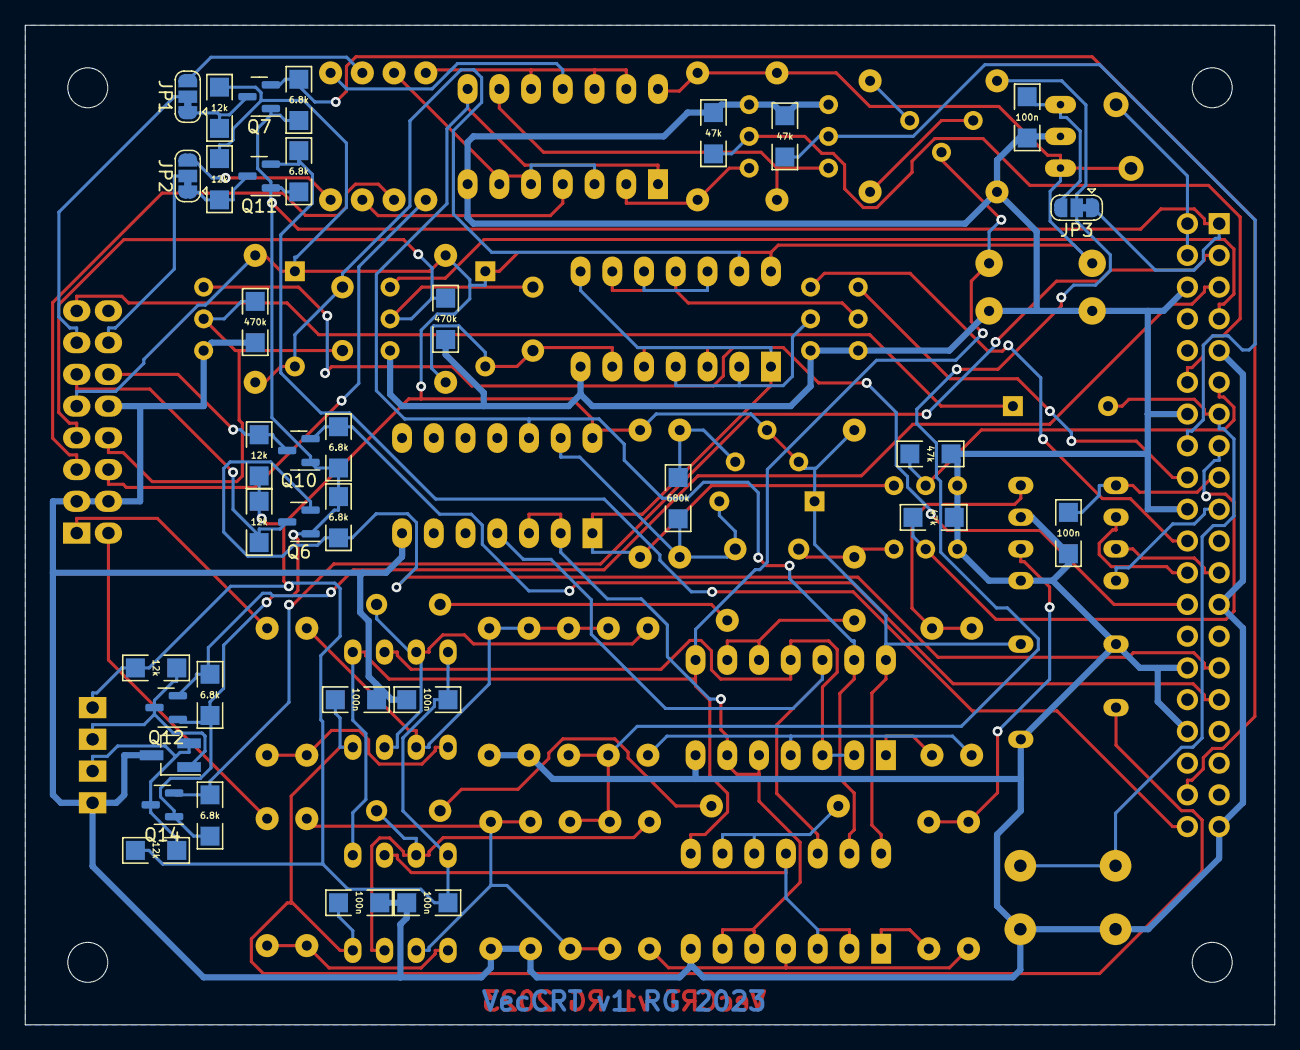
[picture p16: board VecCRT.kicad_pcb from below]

Board: 2 copper layers, 100.0 x 80.0 mm, 108 parts (10 on the bottom side), 83 nets.

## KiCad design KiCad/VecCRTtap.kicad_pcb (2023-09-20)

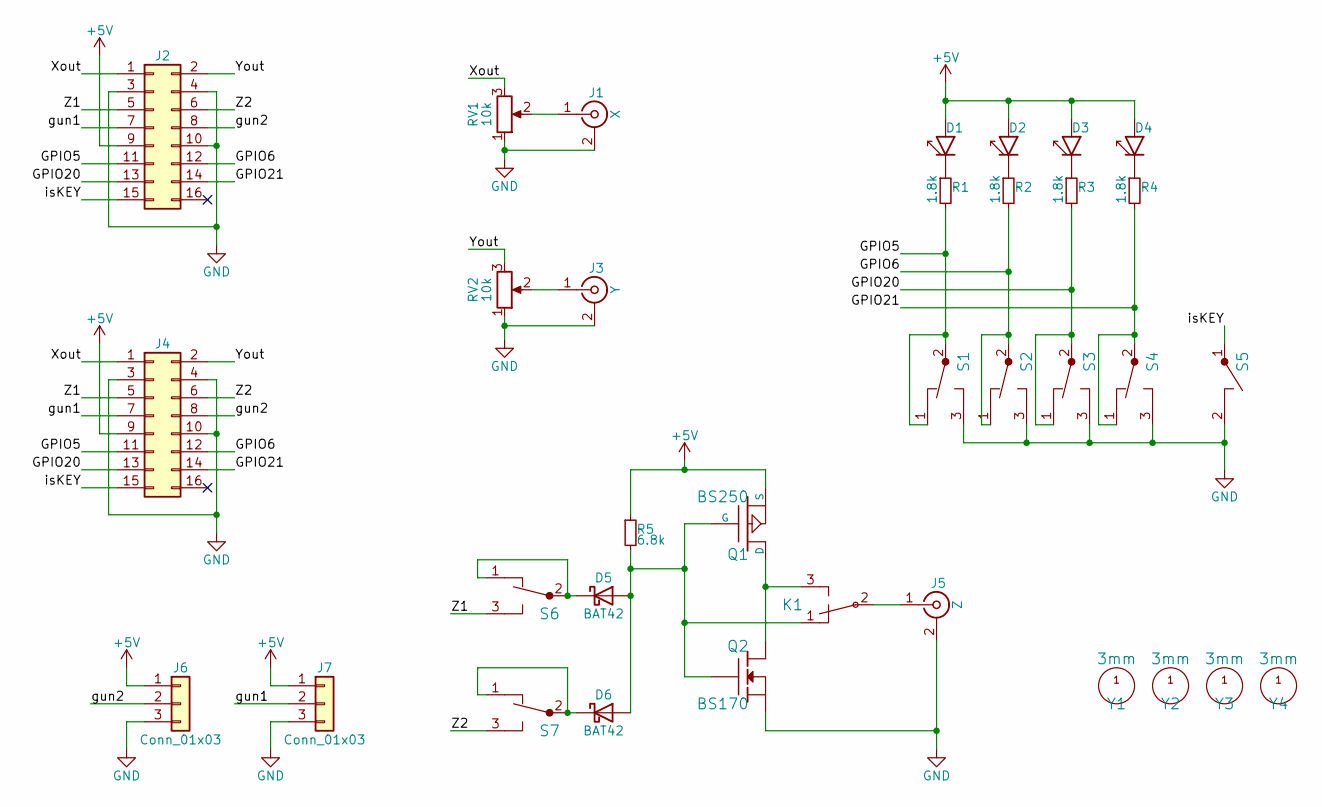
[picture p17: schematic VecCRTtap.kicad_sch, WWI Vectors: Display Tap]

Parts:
D1, D2, D3, D4: LED; LED_D5.0mm
D5, D6: BAT42; D3
J1: X; Cinch_liegend
J2, J4: Conn_02x08_Odd_Even; Wannenstecker_2x08_V
J3: Y; Cinch_liegend
J5: Z; Cinch_liegend
J6, J7: Conn_01x03; PSS_3W
K1: 1UM; Pins_3
Q1: BS250; FETdgs_inline
Q2: BS170; FETdgs_inline
R1, R2, R3, R4: 1.8k; R4-2
R5: 6.8k; R4-2
RV1, RV2: 10k; ACP-CA9V10-Trimmer
S1, S2, S3, S4, S6, S7: TASTERU; Sw-T101-Um
S5: TASTER; SW_MEC_5GTH9
Y1, Y2, Y3, Y4: 3mm; Bohrloch3mm

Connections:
+5V: D1.A, D2.A, D3.A, D4.A, J2.9, J4.9, J6.1, J7.1, Q1.S, R5.1
/GPIO5: J2.11, J4.11, R1.2, S1.1, S1.2
/GPIO6: J2.12, J4.12, R2.2, S2.1, S2.2
/GPIO20: J2.13, J4.13, R3.2, S3.1, S3.2
/GPIO21: J2.14, J4.14, R4.2, S4.1, S4.2
/Xout: J2.1, J4.1, RV1.3
/Yout: J2.2, J4.2, RV2.3
/Z1: J2.5, J4.5, S6.3
/Z2: J2.6, J4.6, S7.3
/gun1: J2.7, J4.7, J7.2
/gun2: J2.8, J4.8, J6.2
/isKEY: J2.15, J4.15, S5.1
GND: J1.2 (Ext), J2.3, J2.4, J2.10, J3.2 (Ext), J4.3, J4.4, J4.10, J5.2 (Ext), J6.3, J7.3, Q2.S, RV1.1, RV2.1, S1.3, S2.3, S3.3, S4.3, S5.2
unnamed: D1.K, R1.1
unnamed: D2.K, R2.1
unnamed: D3.K, R3.1
unnamed: D4.K, R4.1
unnamed: D5.1 (K), S6.1, S6.2
unnamed: D5.2 (A), D6.2 (A), K1.1, Q1.G, Q2.G, R5.2
unnamed: D6.1 (K), S7.1, S7.2
unnamed: J1.1 (In), RV1.2
unnamed: J3.1 (In), RV2.2
unnamed: J5.1 (In), K1.2
unnamed: K1.3, Q1.D, Q2.D

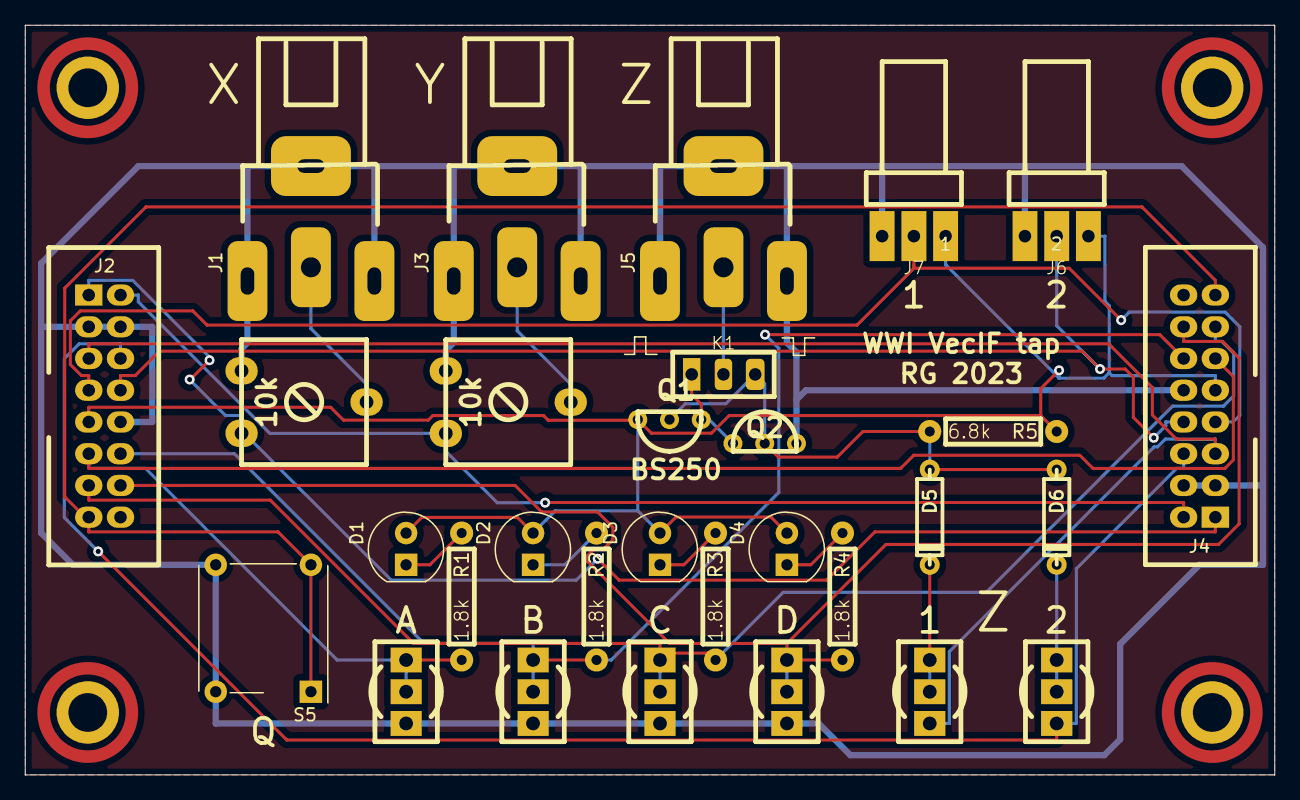
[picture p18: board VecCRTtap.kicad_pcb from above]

Board: 2 copper layers, 100.0 x 60.0 mm, 34 parts (0 on the bottom side), 24 nets.

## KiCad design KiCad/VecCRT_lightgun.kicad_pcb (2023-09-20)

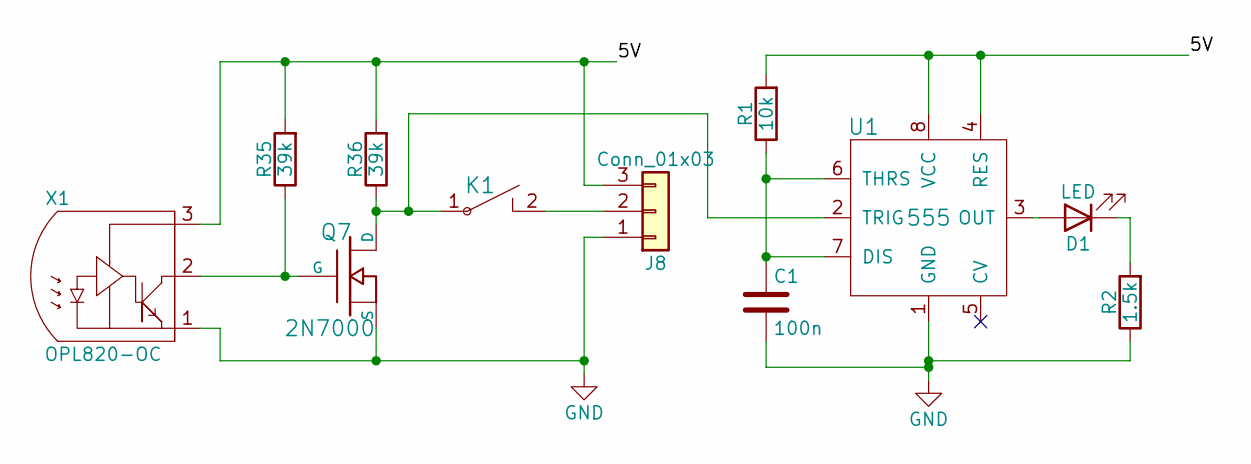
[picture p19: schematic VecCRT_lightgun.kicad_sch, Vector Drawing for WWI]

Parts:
C1: 100n; C2-2
D1: LED; Pins_2
J8: Conn_01x03; Pins_3
K1: SchEin; Pins_2
Q7: 2N7000; FETsgd_inline
R1: 10k; R4-2
R2: 1.5k; R4-2
R35, R36: 39k; R4-2
U1: 555; DIP-8_300
X1: OPL820-OC; Pins_3

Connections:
/5V: J8.3, R1.2, R35.2, R36.2, U1.4 (RES), U1.8 (VCC), X1.3
GND: C1.2, J8.1, Q7.S, R2.1, U1.1 (GND), X1.1
unnamed: C1.1, R1.1, U1.6 (THRS), U1.7 (DIS)
unnamed: D1.1 (K), R2.2
unnamed: D1.2 (A), U1.3 (OUT)
unnamed: J8.2, K1.2
unnamed: K1.1, Q7.D, R36.1, U1.2 (TRIG)
unnamed: Q7.G, R35.1, X1.2

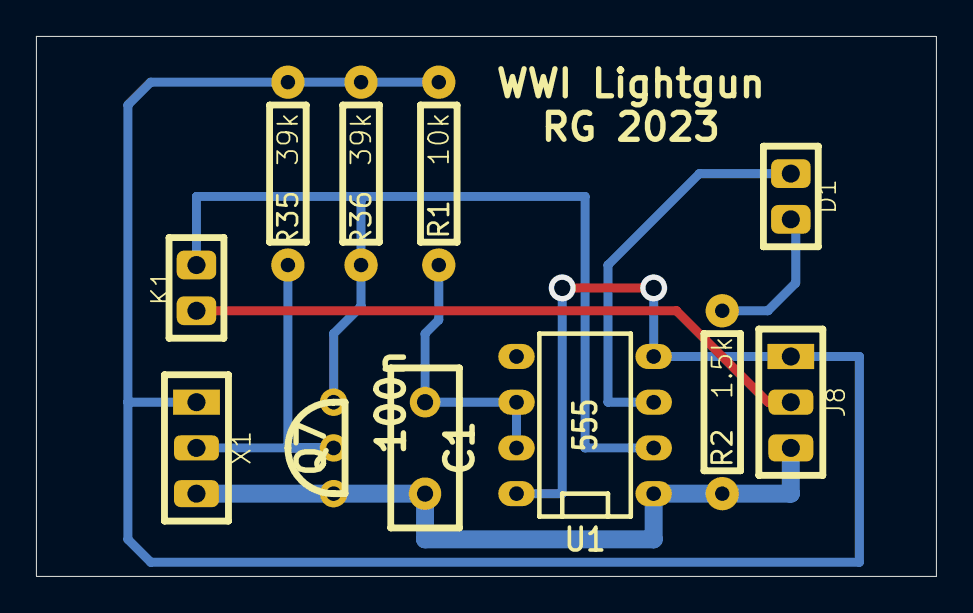
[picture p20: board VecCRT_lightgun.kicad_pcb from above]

Board: 2 copper layers, 50.0 x 30.0 mm, 11 parts (0 on the bottom side), 8 nets.

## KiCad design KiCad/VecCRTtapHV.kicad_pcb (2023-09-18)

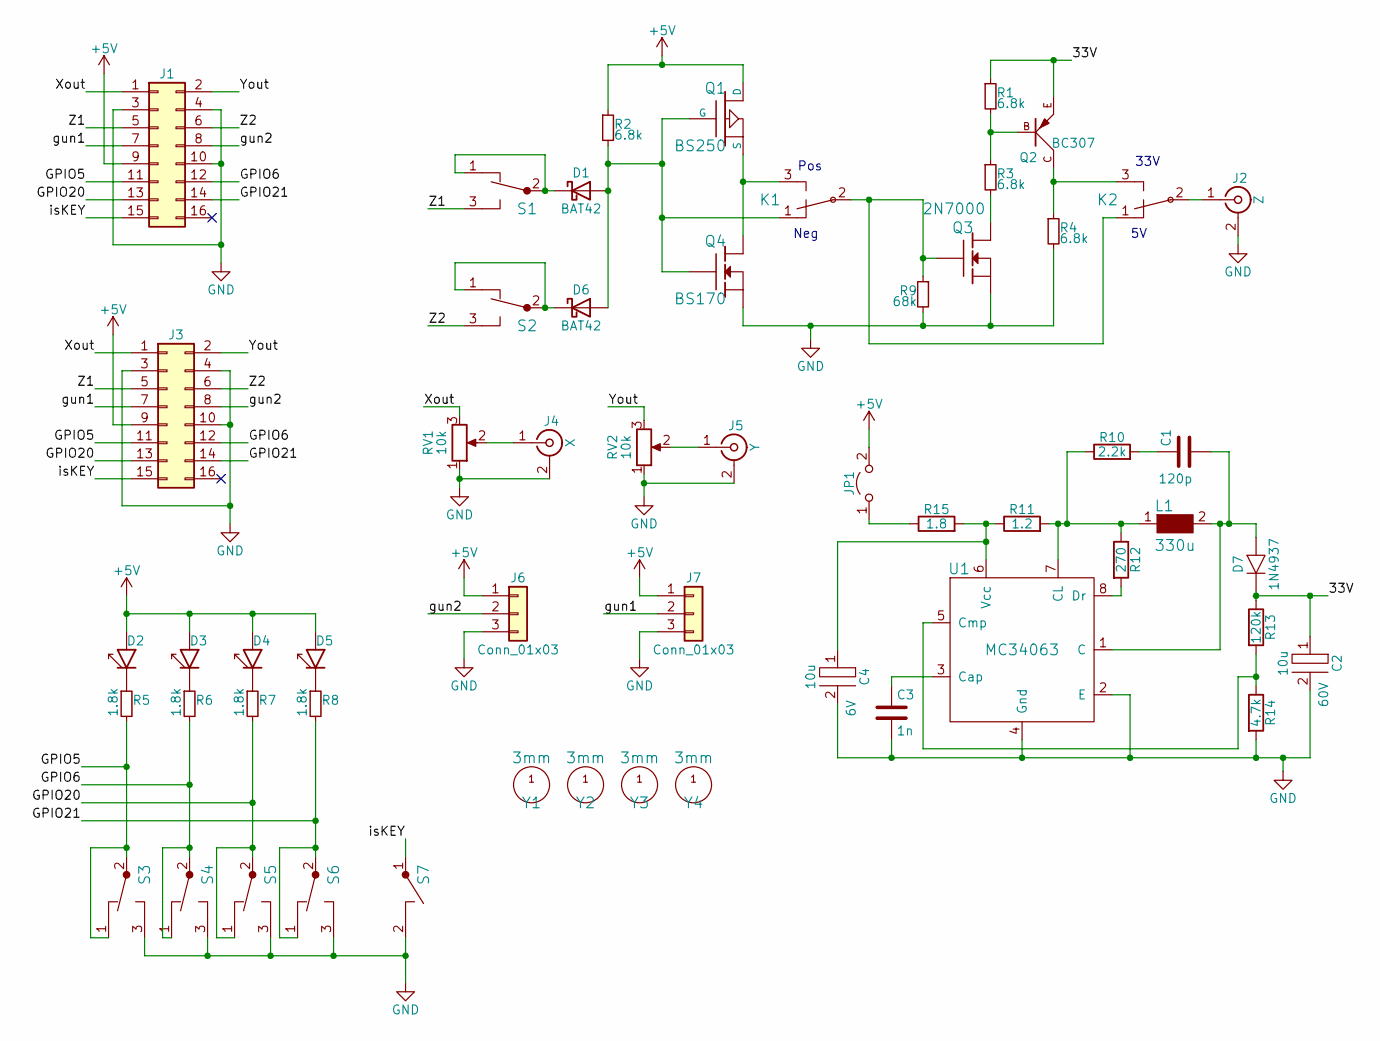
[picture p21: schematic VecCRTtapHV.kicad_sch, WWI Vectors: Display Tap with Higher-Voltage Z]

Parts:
C1: 120p; C2-2
C2: 10u; C2-7; Voltage 60V
C3: 1n; C2-2
C4: 10u; C2-7; Voltage 6V
D1, D6: BAT42; D3
D2, D3, D4, D5: LED; LED_D5.0mm
D7: 1N4937; D_DO-35_SOD27_P7.62mm_Horizontal
J1, J3: Conn_02x08_Odd_Even; Wannenstecker_2x08_V
J2: Z; Cinch_liegend
J4: X; Cinch_liegend
J5: Y; Cinch_liegend
J6, J7: Conn_01x03; PSS_3
JP1: Jumper_2_Open; Pins_2
K1, K2: 1UM; Pins_3
L1: 330u; C2-7
Q1: BS250; FETsgd_inline
Q2: BC307; TO-92_RG_EBC
Q3: 2N7000; FETsgd_inline
Q4: BS170; FETsgd_inline
R1, R2, R3, R4: 6.8k; R4-2
R5, R6, R7, R8: 1.8k; R4-2
R9: 68k; R4-2
R10: 2.2k; R4-2
R11: 1.2; R4-2
R12: 270; R4-2
R13: 120k; R4-2
R14: 4.7k; R4-2
R15: 1.8; R4-2
RV1, RV2: 10k; ACP-CA9V10-Trimmer
S1, S2, S3, S4, S5, S6: TASTERU; Sw-T101-Um
S7: TASTER; SW_MEC_5GTH9
U1: MC34063; DIP-8_300
Y1, Y2, Y3, Y4: 3mm; Bohrloch3mm

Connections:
+5V: D2.A, D3.A, D4.A, D5.A, J1.9, J3.9, J6.1, J7.1, JP1.2 (B), Q1.D, R2.1
/33V: C2.1, D7.1 (K), Q2.E, R1.1, R13.1
/GPIO5: J1.11, J3.11, R5.2, S3.1, S3.2
/GPIO6: J1.12, J3.12, R6.2, S4.1, S4.2
/GPIO20: J1.13, J3.13, R7.2, S5.1, S5.2
/GPIO21: J1.14, J3.14, R8.2, S6.1, S6.2
/Xout: J1.1, J3.1, RV1.3
/Yout: J1.2, J3.2, RV2.3
/Z1: J1.5, J3.5, S1.3
/Z2: J1.6, J3.6, S2.3
/gun1: J1.7, J3.7, J7.2
/gun2: J1.8, J3.8, J6.2
/isKEY: J1.15, J3.15, S7.1
GND: C2.2, C3.2, C4.2, J1.3, J1.4, J1.10, J2.2 (Ext), J3.3, J3.4, J3.10, J4.2 (Ext), J5.2 (Ext), J6.3, J7.3, Q3.S, Q4.S, R4.2, R9.2, R14.2, RV1.1, RV2.1, S3.3, S4.3, S5.3, S6.3, S7.2, U1.2 (E), U1.4 (Gnd)
unnamed: C1.1, R10.2
unnamed: C1.2, D7.2 (A), L1.2, U1.1 (C)
unnamed: C3.1, U1.3 (Cap)
unnamed: C4.1, R11.1, R15.2, U1.6 (Vcc)
unnamed: D1.1 (K), S1.1, S1.2
unnamed: D1.2 (A), D6.2 (A), K1.1, Q1.G, Q4.G, R2.2
unnamed: D2.K, R5.1
unnamed: D3.K, R6.1
unnamed: D4.K, R7.1
unnamed: D5.K, R8.1
unnamed: D6.1 (K), S2.1, S2.2
unnamed: J2.1 (In), K2.2
unnamed: J4.1 (In), RV1.2
unnamed: J5.1 (In), RV2.2
unnamed: JP1.1 (A), R15.1
unnamed: K1.2, K2.1, Q3.G, R9.1
unnamed: K1.3, Q1.S, Q4.D
unnamed: K2.3, Q2.C, R4.1
unnamed: L1.1, R10.1, R11.2, R12.1, U1.7 (CL)
unnamed: Q2.B, R1.2, R3.1
unnamed: Q3.D, R3.2
unnamed: R12.2, U1.8 (Dr)
unnamed: R13.2, R14.1, U1.5 (Cmp)

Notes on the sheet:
Pos
33V
Neg

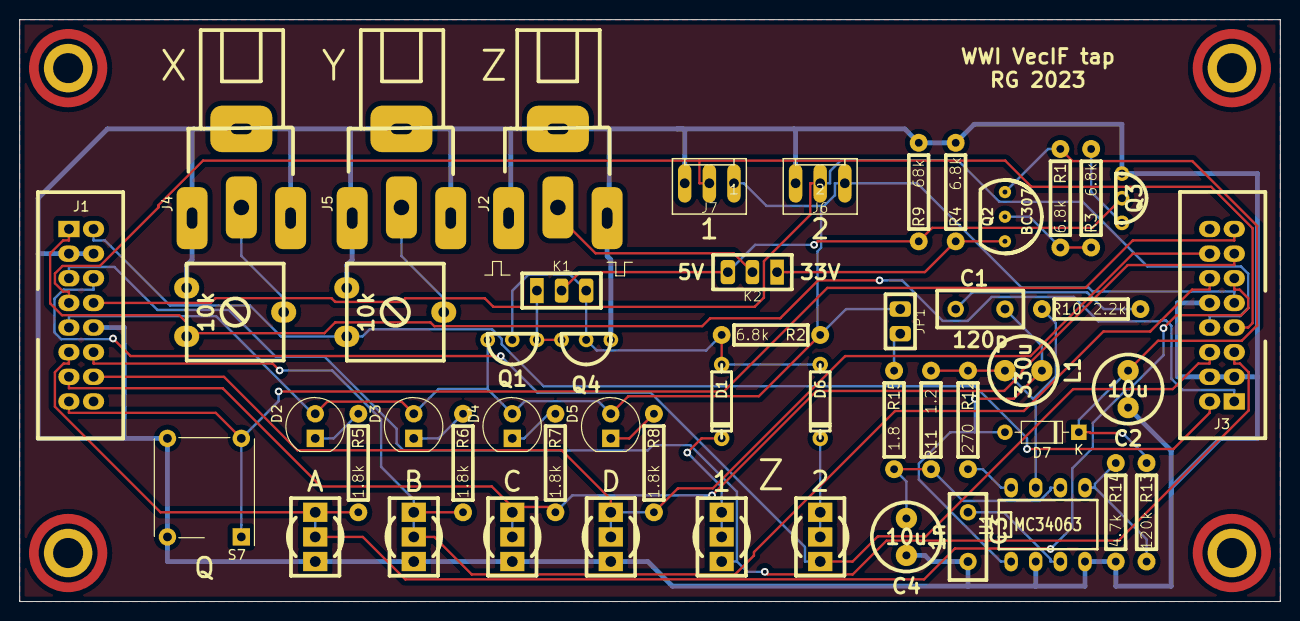
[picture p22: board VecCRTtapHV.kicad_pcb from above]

Board: 2 copper layers, 130.0 x 60.0 mm, 55 parts (0 on the bottom side), 37 nets.

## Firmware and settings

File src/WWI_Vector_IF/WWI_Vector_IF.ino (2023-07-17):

/*
    CRT vector interface for Whirlwind
    
Versions:
    0.1a:   new hardware
    0.1c:   inverted voltages 
    1.1a:   with PCB, light pin low active
*/

#include <limits.h>
const char version [] = "1.1b";

#include <SPI.h>
#define SPI_speed 1000000       // SPI clock speed < 4 MHz
// #define SPI_MOSI 17
// #define SPI_SCK 13
// #define SPI_SS 10


// control pins
const int pinPos = A3;   
const int pinMove = A2;
// light gun pin
const int lightPin = 4;

// Key to cycle through modes
const int keyPin = 3;

// Toggle debug output to serial
bool do_debug = false;

/*
    Wait for a short  (< 0.3sec) keypress
*/
void wait_key() {
    while (digitalRead(keyPin) == HIGH);
        delay(300);     // debounce and skip short press
}

/*
    Sets D/A outputs by SPI
    Inputs is an integer fixed point number between -1 and +1,
    i.e. scaled by 10^15: -INT_MAX .. +INT_MAX
    that sets the output to 2.5V +/- 2.5V V.
    As the DA converter expects a 12-bit integer between 0 and 4095,
    -32768 correpsonds to 0, and +32768 to 4095.  
    The value is negated for hardware reasons.
*/
void setDAbySPI(int valx, int valy) {
  unsigned int sendword;

  // activate chip select 
  digitalWrite(SS, LOW);

  // send 16 bits
  SPI.beginTransaction(SPISettings(SPI_speed, MSBFIRST, SPI_MODE0));
  
  sendword = 2048 - valx / 16; 
  // Serial.println(sendword, HEX);
  SPI.transfer16(sendword | 0x3000 | 0x8000);            // DA0 

  SPI.endTransaction();
          
  // deactivate cip select   
  digitalWrite(SS, HIGH); 
  // delayMicroseconds(20);
  
  // activate chip select 
  digitalWrite(SS, LOW);

  // send 16 bits
  SPI.beginTransaction(SPISettings(SPI_speed, MSBFIRST, SPI_MODE0));
  
   sendword = 2048 - valy / 16; 
  // Serial.println(sendword, HEX);
  SPI.transfer16(sendword | 0x3000 | 0x0000);   // DA1 
  SPI.endTransaction();

  digitalWrite(SS, HIGH);

}

/*  Illuminate a point
    x and y are fixed point as in WWI, i.e. scaled by 2^-15
    32767 is +0.99997 and -32767 is -0.99997
    Produce a strobe for 50µs, then set the negative for AC inputs.
*/
void showPoint(int x, int y) {
    // draw twice for more intensity
    drawVector(x, y, 0, 0);
     
/*
    // second strobe  
    digitalWrite(pinMove, HIGH);
    delayMicroseconds(60);
    digitalWrite(pinMove, LOW);
  */      
}

/*  Draw a (short) vector
 *   
 */
void drawVector(int x, int y, int speedx, int speedy) {
    setDAbySPI(x, y);
    digitalWrite(pinPos, HIGH);
    delayMicroseconds(30 );
    digitalWrite(pinPos, LOW);
    setDAbySPI(speedx, speedy);             
    // delayMicroseconds(30);
    digitalWrite(pinMove, HIGH);
    delayMicroseconds(60); 
    digitalWrite(pinMove, LOW);         
}
   
/* convert floating point to fixed point, i.e. 
*/
int floatfix(float x) {
    if (x >= 1.0)
        return 32767;
    if (x <= -1.0)
        return -32767;
    return round(x * 32767);
}

/*  
    Illuminate a point by float input 
*/
void showFPoint(float x, float y) {
    showPoint(floatfix(x), floatfix(y));
  
}

const float xslope = 4.0, yslope = 4.0;
void drawFVector(float x0, float y0, float x1, float y1) {  
    const float xmax = 1.0 / xslope; 
    const float ymax = 1.0 / yslope;
    float dx = x1 - x0;
    float dy = y1 - y0;
    if (abs(dx) < 0.01 + xmax && abs(dy) < 0.01 + ymax) {
        drawVector(floatfix(x0), floatfix(y0), floatfix(xslope*dx), floatfix(yslope*dy));
        return;
    }
    /*
    dx = dx / 4.0;
    dy = dy / 4.0;
    drawFVector(x0, y0, x0+dx, y0+dy);
    x0 += dx;
    y0 += dy; 
    drawFVector(x0, y0, x0+dx, y0+dy);
    x0 += dx;
    y0 += dy; 
    drawFVector(x0, y0, x0+dx, y0+dy);
    x0 += dx;
    y0 += dy; 
    drawFVector(x0, y0, x0+dx, y0+dy);

    */
    // use same length segments
    int xsegs = abs(dx * xslope)+0.99;
    int ysegs = abs(dy * yslope)+0.99;
    int segs = xsegs;
    if (ysegs > segs)
        segs = ysegs;
    if (segs < 1) {
        Serial.print("??? segs=");
        Serial.print(segs);
        Serial.print(" dx=");
        Serial.print(dx);
        Serial.print(" ");
        Serial.print(dx*xslope);
        Serial.print(" dy=");
        Serial.print(dy);
        Serial.print(" ");
        Serial.println(dy*yslope); 
    }
    dx = dx / segs;
    dy = dy / segs;
    
    while (segs > 0)  {

       float x1 = x0 + dx;
       float y1 = y0 + dy;
       drawFVector(x0, y0, x1, y1);
       x0 = x1;
       y0 = y1; 
       --segs;
    }
    
}
                    

/**
  Draw an arc with center at (x,y) and radius r.
  Start with angle (startArc) and end at (endArc). 
  
**/
void draw_arc(float x0, float y0, float r, float startArc, float endArc) {
    // the number of points for a full circle
    int points = 60.0 * r;
    // use a minimum of points
    if (points < 6) points = 6;
    long int start = millis();
    float x1 = x0;
    float y1 = y0 + r;
    for (int i = 1; i<=points; ++i) {
        float t;
        t = i * (6.282 / points);
        print(t, i, points)
        float x2 = x0+r*sin(t);
        float y2 = y0+r*cos(t);
        drawFVector(x1, y1, x2, y2);
        x1 = x2;
        y1 = y2;
    }  

}

/**
  Draw a circle with center at (x,y) and radius r. 
**/
void draw_circle(float x0, float y0, float r) {
    // number of vectors
    int points = 60.0 * r;
    // use a minimum of points
    if (points < 6) points = 6;
    
    float x1 = x0;
    float y1 = y0 + r;
    for (int i = 1; i<=points; ++i) {
        float t;
        t = i * (6.282 / points);
        float x2 = x0+r*sin(t);
        float y2 = y0+r*cos(t);
        drawFVector(x1, y1, x2, y2);
        x1 = x2;
        y1 = y2;
    }  

}
 
/*
  Draw a straight line by a given number of points (not a vector)
*/
void draw_line_points(float x1, float y1, float x2, float y2, int points) {
    int cnt;
    float ix = (x2 - x1) / points;
    float iy = (y2 - y1) / points;
    for (cnt = 1; cnt <= points; ++cnt) {
        float x, y;
        x = x1 + ix * cnt;
        y = y1 + iy * cnt;
        showFPoint(x, y);
    }
}

/* 
  Draw a line with default number of points
*/
void draw_line(float x1, float y1, float x2, float y2) {
    drawFVector(x1, y1, x2, y2);
    return;
    float len = sqrt((x2-x1)*(x2-x1) + (y2-y1)*(y2-y1));
    // use 40 per full horizontal and vertical line, thus 56 per diagonal
    int points = len*20.0;
    if (do_debug) {
        Serial.print("Line points:");
        Serial.println(points);
        }
    draw_line_points(x1, y1, x2, y2, points);
}


/* 
 *  7-segment Charactor Generator
 *  
 */
const float chardelta = 50.0 / 1024.0;
float mvxtab[8] = { 0, chardelta, 0, -chardelta, 0, chardelta, 0};
float mvytab[8] = { -chardelta, 0, chardelta, 0, chardelta, 0, -chardelta };
void drawCharacter(float x0, float y0, byte segs) {
    
    byte mask = 0x40;
    float x1 = x0;
    float y1 = y0;
    float x2, y2;
    // Serial.println(segs, BIN);
    for (int i=0; i < 8; ++i) {
        x2 = x1 + mvxtab[i];
        y2 = y1 + mvytab[i];

        if (mask & segs) {
            /*
            Serial.print(mvxtab[i]);
            Serial.print(":");
            Serial.print(mvytab[i]);
            Serial.print(" ");
            Serial.print(x1);
            Serial.print("/");
            Serial.print(y1);
            Serial.print(" -> ");
            Serial.print(x2);
            Serial.print("/");
            Serial.print(y2);
            Serial.print(" & ");
            Serial.println(mask);
            */
            drawFVector(x1, y1, x2, y2);
        }
        mask = mask >> 1;
        x1 = x2;
        y1 = y2;
    }
}

byte digits[10] = { 0b1110111, 0b0010001, 0b1101011, 0b0111011, 0b0011101,
                    0b0111110, 0b1111110, 0b0010011, 0b1111111, 0b0111111  };


void drawRect(float x, float y, float dx, float dy) {
   draw_line(x-dx, y-dy, x+dx, y-dy);
   draw_line(x-dx, y+dy, x+dy, y+dy);   
   draw_line(x+dx, y-dy, x-dx, y-dy);
   draw_line(x-dx, y+dy, x+dx, y+dy);                
}

/** 
    OXO / noughts and crosses /  tic-tac-toe
    Radom computer play
**/

enum oxo_what { oxo_free, oxo_nought, oxo_cross};
enum oxo_what oxo_state[9];
const float oxo_rad = 0.15;

int oxo_show() {
    int rc = -1;
    int i;
    for (i = 0; i < 9; ++i) {
        float x = 0.5 * (-1 + i % 3);
        float y = 0.5 * (1 - i / 3);
        if (do_debug) {
            Serial.print(i);
            Serial.print(": ");
            Serial.print(x);
            Serial.print(", ");
            Serial.print(y);
            Serial.print(" -> ");
            Serial.println(oxo_state[i]);
        }
        switch (oxo_state[i]) {
            case oxo_free: 
                // need point for light gun
                showFPoint(x, y);
                if (digitalRead(lightPin) == LOW)
                    rc = i;
                break;
            case oxo_nought:
                draw_circle(x, y , oxo_rad);
                // showFPoint(x, y);
                break;
            case oxo_cross:
                // drawRect(x, y, oxo_rad*1.3, oxo_rad*1.3);
                // as four lines from the middle
                drawFVector(x, y, x+oxo_rad, y+oxo_rad);
                drawFVector(x, y, x+oxo_rad, y-oxo_rad);
                drawFVector(x, y, x-oxo_rad, y+oxo_rad);
                drawFVector(x, y, x-oxo_rad, y-oxo_rad);
                // showFPoint(x, y);
                break;
        }  
    }
    return rc;
}

/*  
    play oxo
*/
void do_oxo() {
    // testing: just show a random pattern
    for (int i=0; i < 9; ++i) {
        oxo_state[i] = (enum oxo_what) random (oxo_free, oxo_cross+1);
        }
    while (digitalRead(keyPin) == HIGH) {
        int hit = oxo_show();
        if (hit >= 0)
            oxo_state[hit] = (enum oxo_what) random (oxo_nought, oxo_cross+1);
        // clear if full
        bool isfull = true;
        for (int i=0; i < 9; ++i) { 
            if (oxo_state[i] == oxo_free) {
                isfull = false;
                break;
            }
        }
        if (isfull) {
            for (int i=0; i < 9; ++i)
                oxo_state[i] = oxo_free;
        } 
    }
    
    // delay(300);
}
    

/**
    Bouncing ball 
    The ground line is drawn stepwise with each y-point
**/

void do_bounce() {
  
    const float gravi = 0.02;
    const float ground = -0.5;
    const float repel = -0.8;     // reflection on ground with loss 
    const float xstep = 0.02;      // advance in x direction
    const float xborder = 0.9;    // right border = - left border

    static float xpos = 1.0;       // restart
    static float ypos; 
    static float yspeed;  

    
   // compute speed
    yspeed += gravi;

    // compute position
    ypos -= yspeed;
    if (ypos < ground) {
        yspeed = yspeed * repel;
        ypos = ground;
    }            
        
    // advance x
    xpos += xstep;
    
    // check if start or restart 
    if (xpos > xborder) {
        xpos = -xborder;
        ypos = 0.6;
        yspeed = 0.1;
        // Serial.println("Ground ");
    }

    // plot the point
    showFPoint(xpos, ypos);
    // plot the x-axis
    showFPoint(xpos, ground);

    if (do_debug) {
        Serial.print("x:");
        Serial.print(xpos);
        Serial.print(", y:");
        Serial.print(ypos);
        Serial.print(", v:");
        Serial.print(yspeed);
        Serial.println();
        delay(50);
    }
       
}

// convert degreed to radians
float deg2rad(float x) {
    return 6.282*x/360;
}

/*
  Simple ballistic Rocket launch
  without air resistance
*/
void do_rocket(int mode) {
    // gravitation 
    const float grav = 0.003;
    // launch angle in degrees
    const float launchdir = 87.0;
    // fuel left
    float fuel = 1.0;
    // rocket speed
    float xspeed = 0.0, yspeed = 0.0;
    // rocket position
    float xpos = -0.9, ypos = 0.0;
    // acceleration per fuel unit
    const float accel = 0.005;
    // 
    const float burn = 0.05;
    
    // upon launch, set inital speeds
    xspeed = 0.01*cos(deg2rad(launchdir));
    yspeed = 0.01*sin(deg2rad(launchdir));

    
    // main loop: accelerate while fuel, show fuel and speed
    while (ypos >= -0.1 && ypos < 1.0 & xpos < 1.0) {
        float speed = sqrt(xspeed*xspeed + yspeed*yspeed);
        // accelerate if still fuel
        if (fuel > 0.0) {
            // no need to calculate flight angle, just the speed
            xspeed += xspeed / speed * accel;
            yspeed += yspeed / speed * accel;
            fuel -= burn;
        }
        // gavitation is always in y direction
        yspeed -= grav;
        
        // integrate to positions
        xpos += xspeed;
        ypos += yspeed;
        
        if (do_debug) {
            Serial.print("speed:");
            Serial.print(xspeed);
            Serial.print(",");
            Serial.print(yspeed);
            Serial.print(" pos:");
            Serial.print(xpos);
            Serial.print(",");
            Serial.print(ypos);
            Serial.print(" fuel:");
            Serial.print(fuel);
            Serial.print(" speed:");
            Serial.print(speed);
            Serial.println();
        }

        /*
         * Display the current state
         */

        // always actual point and base line
        showFPoint(xpos, ypos);
        drawFVector(-1.0, 0.0, 1.0, 0.0);
        drawCharacter(0.0, -0.8, digits[mode]);

        // show fuel as bar at the left side
        drawFVector(-0.99, 0.0, -0.99, fuel);
        showFPoint(-0.99, fuel);   // show end point
        
        
        // mode 0 and 1: 
        if (mode == 0 || mode == 1) {   
            // show velocity
            drawFVector(0.99, 0.0, 0.99, speed*10.0);
            showFPoint(0.99, 0.0 + speed*10.0);
            delay(5);   // compensate for the character display)
        }


        int fueli = fuel*100;
        int speedi = speed*1000;
        
        // mode 1 and 2:
        if (mode == 1 || mode == 2) {
           drawCharacter(-0.9, -0.3, digits[fueli / 10]);
           drawCharacter(-0.8, -0.3, digits[fueli % 10]);
           drawCharacter(0.8, -0.3, digits[speedi / 10]);
           drawCharacter(0.9, -0.3, digits[speedi % 10]);
        } 

        // mode 2: speed vector 
        if (mode == 2) {
            drawFVector(xpos, ypos, xpos + 5*xspeed, ypos + 5*yspeed);          
        }
        if (digitalRead(keyPin) == LOW)
            return;
        
    }
    
    
}


/*
    Central loop
*/
enum Modes{ mode_line, mode_cir, mode_digits, mode_bounce, mode_rocket0, mode_rocket1, mode_rocket2, mode_oxo};
int mode = mode_line;
int oldmode = -1;
void loop() { 

    check_key();                    // advances mode
    switch (mode) {
        case mode_line:
            if (mode != oldmode)
                Serial.println("Line mode");
            draw_line(1.0, 1.0, -1.0, -1.0);
            draw_line(1.0, -1.0, -1.0, 1.0);
            draw_line(0.0, -1.0, 0.0, 1.0);
            draw_line(-1.0, 0.0, 1.0, 0.0);
            draw_line(-0.5, 0.0, 0.0, 0.5);
            draw_line(0.5, 0.0, 0.0, 0.5);
            draw_line(-0.5, 0.0, 0.0, -0.5);
            draw_line(0.5, 0.0, 0.0, -0.5);

            break;
            
        case mode_cir:
            if (mode != oldmode)
                Serial.println("Circle mode");
            draw_circle(0, 0, 1.0);
            draw_circle(0.5, 0.5, 0.2);
            break;
        case mode_digits:
            if (mode != oldmode)
                Serial.println("Digits mode");
            for (int i = 0; i < 10 ;  ++i) {
                drawCharacter(-0.5 + i * 0.1, 0.0, digits[i]);
            }
            delay(20);
            break;
        case mode_bounce:
            if (mode != oldmode)
                Serial.println("Bounce mode");
            do_bounce();
            break;
        case mode_rocket0:
            if (mode != oldmode)
                Serial.println("Rocket mode 0");
            do_rocket(0);
            break;
        case mode_rocket1:
            if (mode != oldmode)
                Serial.println("Rocket mode 1");
            do_rocket(1);
            break;
        case mode_rocket2:
            if (mode != oldmode)
                Serial.println("Rocket mode 2");
            do_rocket(2);
            break;
        case mode_oxo:
            if (mode != oldmode)
                Serial.println("OXO mode");
            do_oxo();
            break;
        default:
            Serial.print("Mode reset: ");
            Serial.println(mode);
            mode = 0;
            oldmode = -1;
            return;
    }
    oldmode = mode;
        
}

/*  
    Check key to advance mode
*/
// very dsimple version
void check_key() {
  if (digitalRead(keyPin) == HIGH)
    return;
  // debounce key press
  delay(30);    
  if (digitalRead(keyPin) == HIGH)
    return;
  // wait for release
  while (digitalRead(keyPin) == LOW)
    ;
  delay(20);    // debounce key relase
  mode += 1;    // any overflow corrected in loop()
  Serial.print("---------> new mode:");
  Serial.println(mode);

  
}


/**
  Initialisierung
**/

void setup() {
  pinMode(LED_BUILTIN, OUTPUT);
  // Serial I/O
  Serial.begin(115200);
  int tries = 20;
  while (--tries && !Serial) {
      // wait for serial port to connect. Needed for native USB
      delay(100);
      digitalWrite(LED_BUILTIN, HIGH);
      delay(100);
      digitalWrite(LED_BUILTIN, LOW);
  }

  // Banner with version information
  Serial.println();
  Serial.println();
  Serial.print("CRT Test ");
  Serial.print(version);
  Serial.print(" Compiled: ");
  Serial.print(__DATE__);
  Serial.print(" ");
  Serial.println(__TIME__);
  Serial.println(MOSI);

  // SPI
  digitalWrite(SS, HIGH);
  pinMode(SS, OUTPUT);
  pinMode(MOSI, OUTPUT);
  pinMode(SCK, OUTPUT);
  
  // SPI initialisieren
  SPI.begin();


  // Position signal
  digitalWrite(pinPos, LOW);
  pinMode(pinPos, OUTPUT);

  // Move signal
  digitalWrite(pinMove, LOW);
  pinMode(pinMove, OUTPUT);
  
  // key pin
  pinMode(keyPin, INPUT_PULLUP);
  digitalWrite(keyPin, HIGH);

  // light gun pin
  pinMode(lightPin, INPUT_PULLUP);
  digitalWrite(lightPin, HIGH);
  
  // set debug mode if key is pressed on reset
  if (digitalRead(keyPin) == LOW)
    do_debug = true;

    

}

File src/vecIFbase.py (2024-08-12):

#!/usr/bin/env python3
# vi: ts=4
""" Basic functions for vector interface
"""

# 
import RPi.GPIO as gpio
import spidev
import time
import math
import random

#
version = "0.3a"

move_delay = 15   # .0E-6     # wait to settle after a new position
draw_delay = 55   # .0E-6     # >50 us to do a stoke
hold_delay = 10   # .0E-6     # one-shot recovery time
 
# pin definitions in BCM numbering
pin_doMove = 17
pin_doDraw = 22
pin_enZ1 = 18
pin_enZ2 = 23
pin_isKey = 27
pin_isGun1 = 25
pin_isGun2 = 24
pin_isGun1on = 4
pin_isGun2on = 7
pin_LED1 = 5
pin_LED2 = 6
pin_LED3 = 20
pin_LED4 = 21
# SPI pins are defined by SPI interface

 
def floatfix(x):
    """ Converts floating point number to integer for D/A converter
        -1.0 ... +1.0 becomes 2048 +/- 2048
    """
    if (x > 1.0):
        return 4095;
    if (x < -1.0):
        return 0;
    return 2048 - int(x*2047);
    
def setDA(n, val):
    """ sets one D/A converter
        n: 0 or 1 for converter number
        val: float -1.0 ... +1.00
    """
    ival = floatfix(val)
    hival = ival // 256
    loval = ival % 256
    mask = 0x30
    if (n == 0):
        mask = mask | 0x80
    outv = [mask | hival, loval]
    spi.writebytes(outv)
    
    
def delay_us(duration):
    """ the time.sleep() function is not accurate enough,
    and there is nothing more to be done.
    So busy waiting is used.
    """
    stop = time.perf_counter_ns() + 1000 * duration
    while time.perf_counter_ns() < stop:
        time.sleep(0)
        
def movePoint(posx, posy):
    # move to destination
    setDA(0, posx)
    setDA(1, posy)
    gpio.output(pin_doMove, 1)
    delay_us(move_delay)
    gpio.output(pin_doMove, 0)
                        
def drawSegment(speedx, speedy):		
    # set speed
    setDA(0, speedx)
    setDA(1, speedy)
    gpio.output(pin_doDraw, 1)
    delay_us(draw_delay)
    gpio.output(pin_doDraw, 0)
    
def setOutLine(line):
    """ Enables or disbles output lines
        Input is a bit pattern, bit 0 for line 1, bit 1 for line 2
        i.e. 0 for none, 1 for 1, 2 for 2 and 3 for both
    """
    if line == 1 or line == 3:
        gpio.output(pin_enZ1, 0)  # inverted: 0 is enable, 1 is disable
    else:
        gpio.output(pin_enZ1, 1)  
    if line == 2 or line == 3:
        gpio.output(pin_enZ2, 0)
    else:
        gpio.output(pin_enZ2, 1)  
        
        
wasPoint = False        # true after a point drawing

def drawSmallVector(posx, posy, speedx, speedy):
    """ Basic operation: Draw a vector with given speed
        As the endpoint is not directly given,
        but as a speed, the length is limited 
        so that the endpoint can be predicted precise enough.
        The draw mechanism draws for 50µs;
        with maximum speed, it draws 1/8 of the screen width.
        To draw a point, use zero speeds
    """
    movePoint(posx, posy)
    drawSegment(speedx, speedy)

    # reset point drawing flag
    global wasPoint
    wasPoint = False


    
def drawPoint(posx, posy):
    """ draw a point as a vector of length 0
    """

    drawSmallVector(posx, posy, 0.0, 0.0)
    
    # last one was a point drawing    
    global wasPoint
    wasPoint = True


        
"""
    The light gun has a trigger switch for one-shot operation:
    Only the first pulse after display of a point is valid;
    more are to be disabled while the trigger switch is still on.
    
    As no pulses are transmitted before the switch is on,
    the first such pulse (after display of a point) sets a flag
    to disable more (of this light gun).
    
    This flag is reset once the switch is off more than 50msec (debouncing)
"""

wasGunPulse1 = True          # if a pulse was delivered
gunTime1= 0.0
wasGunPulse2 = True          # if a pulse was delivered
gunTime2= 0.0
debounceGunTime = 0.05
    
  
def getLightGuns():
    """
        returns 0 if no light gun detected, or set the (two) lower bits
        
    """  
    global wasPoint, wasGunPulse1, gunTime1, wasGunPulse2, gunTime2, debounceTime
    # light gun signals are evaluated only if there was a point drawing
    if not wasPoint:
        return 0
    
    mask = 0
    # check if this is the first light gun pulse
    if not wasGunPulse1 and gpio.input(pin_isGun1) == 0:
        mask = 1
        wasGunPulse1 = True
    if not wasGunPulse2 and gpio.input(pin_isGun2) == 0:
        mask = mask | 2
        wasGunPulse2 = True
        
    if mask != 0:
        return mask
    
    # print(gpio.input(pin_isGun1on), gpio.input(pin_isGun2on))
    # debounce switch 1 
    if gpio.input(pin_isGun1on) == 0:
        # while switch is on, restart timer
        gunTime1 = time.time()
    else:
        # switch must be off some time (debounce)
        delta = time.time() - gunTime1
        if delta > debounceGunTime:
            wasGunPulse1 = False
            
    # debounce switch 2
    if gpio.input(pin_isGun2on) == 0:
        # while switch is on, restart timer
        gunTime2 = time.time()
    else:
        # switch must be off some time (debounce)
        delta = time.time() - gunTime2
        if delta > debounceGunTime:
            wasGunPulse2 = False

    return 0
        
def getKeys():
    """ Key inquiry for the push button on the interface board
    and the four switches on the tap board(s).
    Result in a bit pattern with LSB for the push button
    and the other four keys, left to right, with 2, 4, 8, and 16.
    Note that setKeys() can virtually set a key
    """
    res = 0 
    if gpio.input(pin_isKey) == 0:
        res = 1
    if gpio.input(pin_LED1) == 0:
        res += 2
    if gpio.input(pin_LED2) == 0:
        res += 4
    if gpio.input(pin_LED3) == 0:
        res += 8
    if gpio.input(pin_LED4) == 0:
        res += 16
        
    return res
    
 
def setKey(n, b):
    """ 
        Set virtual key (i.e. the LED) on (1) or off (0)
    """
    if n == 0:
        return			# ignore key 0
    LEDs = [pin_LED1, pin_LED2, pin_LED3, pin_LED4]
    led = LEDs[n-1]
    if b == 0:
        gpio.setup(led, gpio.IN, pull_up_down=gpio.PUD_UP)
    else:
        gpio.setup(led, gpio.OUT)
        gpio.output(led, 0)
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

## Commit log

2023-07-19 Trigger switch with CMOS
    [Lightgun_bottom.scad, Lightgun_bottom.stl, Lightgun_top.scad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]
2023-07-21 removed trigger switch hardware
    [VecCRTtrigger.kicad_pcb, VecCRTtrigger.kicad_sch, VecCRTtriggerCMOS.kicad_pcb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]
2023-07-21 Schematics as pdf added
2023-07-22 new one-shot light-gun
    [VecCRT.kicad_pcb, VecCRT.kicad_sch]
2023-07-22 Updated schematics pdf
2023-07-24 chain of vectors for character and circle
2023-07-25 minor changes
    [VecCRT.kicad_sch]
2023-08-14 Added lightgun for OPL-820
    [VecCRT.kicad_sch]
2023-08-26 before 1.0
    [Leybold-Amplifier.kicad_pcb, Leybold-Amplifier.kicad_sch, VecCRT.kicad_sch]
2023-08-27 Schematics for 1.0a
    [VecCRT.kicad_sch, VecCRT_lightgun.kicad_sch, VecCRTdrop.kicad_sch]
2023-08-29 1.0c: moved I²C to own bus
    [VecCRT.kicad_sch, VecCRTdrop.kicad_sch, VecCRTtap.kicad_sch]
2023-09-01 KiCad: EDA updates for PCB production; preliminary tap and switches; ReadMe.md updated
    [VecCRT.kicad_pcb, VecCRT.kicad_sch, VecCRTswitches.kicad_sch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]
2023-09-02 revise tap board
    [VecCRTtap.kicad_pcb, VecCRTtap.kicad_sch]
2023-09-02 Enlarge board, larger PB
    [VecCRTtap.kicad_pcb]
2023-09-02 correct tap board pictures
2023-09-08 Cut 3.3 / VccDAC for Arduino test
    [VecCRT.kicad_pcb, VecCRT.kicad_sch]
2023-09-08 lightgun lamp
    [Lightgun_bottom.scad, Lightgun_bottom.stl, Lightgun_top.scad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]
2023-09-13 Update lightgun LED, add HV, fixes
    [Leybold-Amplifier.kicad_sch, VecCRT_lightgun.kicad_pcb, VecCRT_lightgun.kicad_sch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]
2023-09-20 small fixes
    [VecCRT_lightgun.kicad_pcb, VecCRT_lightgun.kicad_sch, VecCRTtap.kicad_pcb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]
2023-10-07 kicad fixes
    [VecCRT.kicad_pcb, VecCRT.kicad_sch]
2023-10-10 button handling in vecIF
2023-10-11 Fixes in Schematics
    [VecCRT.kicad_pcb, VecCRT.kicad_sch]
2024-08-12 Some minor changes
    [Lightgun_bottom.scad, Lightgun_bottom.stl, Lightgun_top.scad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]
2024-08-12 Library of used footprints
2024-08-12 local library for extra symbols
    [VecCRT.kicad_sch]
2024-08-12 Fix symbol reference to local library
    [VecCRT.kicad_sch]
2024-08-15 Templates relative local
    [VecCRT.kicad_sch]
2024-08-15 Remove Leybold Amplifier (should not be here)
    [Leybold-Amplifier.kicad_pcb, Leybold-Amplifier.kicad_sch]
